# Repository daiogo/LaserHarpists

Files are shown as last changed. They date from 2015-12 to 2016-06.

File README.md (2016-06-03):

# What is a laser harp?
A laser harp is a harp that has laser beams emulating the strings of a regular harp. Whenever you intercept a laser beam, a note is played to that correspondent intercepted beam.

# Cool features in our laser harp
- The notes are played by an Android app;
- It's wireless! It communicates with the app via Bluetooth;
- There are ultrasonic range finders that measure the height of your interception;
  - That makes it possible to play 3 notes in a single laser beam.
- There are two modes of operation:
  - Free Play: let your inner Jean Michel Jarre shine (:
  - Learn To Play: learn to play a song in the harp
- RGB LED strips positioned in the front of each laser beam
  - They lit to the note you play when you intercept a laser beam on Free Play mode
  - They lit to the correspondent string and height to be intercepted in the current music

# Pics or it didn't happen
Yes, there's a demo video! Too bad we didn't had the time to learn how to play the harp (:

https://www.youtube.com/watch?v=IKeanOgFvdw

# Bill of materials
- Tiva C Launchpad
- JY-MCU Bluetooth module
- 8 HC-SR04 ultrasonic range finders
- 8 5mW laser diodes
- 8 interception sensors (circuit schematic found inside the repo)
  - comparator IC
  - potentiometer
  - LDR (Light dependent resistor)
  - 0.25W resistors
  - Materials to build a PCB to each interception sensor
- 8 12V RGB LED strips
- 3 high current drivers IC
- 3 shift registers

# Makers
- José Augustinho
  - Firmware programming, PCB confection and project manager
- Rinaldi Segecin
  - Mobile app development, firmware programming
- Diogo Freitas (myself)
  - Hardware development, PCB confection, firmware debugging

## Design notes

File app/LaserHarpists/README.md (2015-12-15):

# LaserHarpists
It's an android app that connects with a laser harp and plays sounds.

Project documented in https://www.sharelatex.com/project/56433206ea53832b060072b0

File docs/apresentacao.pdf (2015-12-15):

# LASERHARPISTS: HARPA ELETRÔNICA

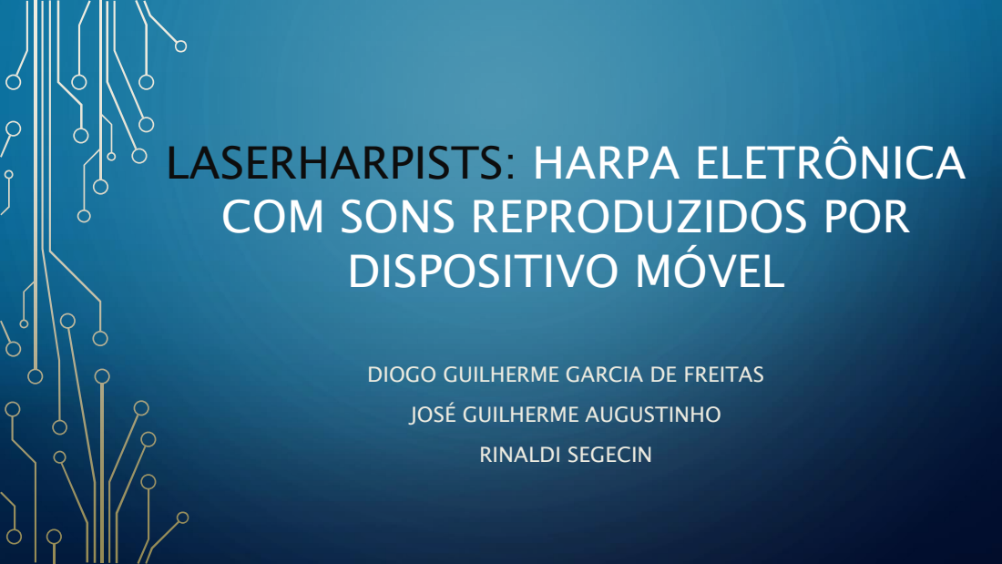
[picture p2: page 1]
RINALDI SEGECIN

COM SONS REPRODUZIDOS POR
DISPOSITIVO MÓVEL

DIOGO GUILHERME GARCIA DE FREITAS
JOSÉ GUILHERME AUGUSTINHO

## SUMÁRIO

- Introdução
- Sistema embarcado
- Visão geral
- Microcontrolador
- Módulo sensorial
- Placa principal
- Firmware
- Visão geral
- Responsabilidades
- A aplicação Android
- Modo Free Style
- Modo Learn to Play
- Resultados
- Conclusão

## INTRODUÇÃO

- Surgimento e popularização da música eletrônica
- Idealização da primeira harpa laser
- Licenciado em 1975
- Popularizado por Jean Michel Jarre
- Objetivos do projeto
- Diferenciais

## VISÃO GERAL

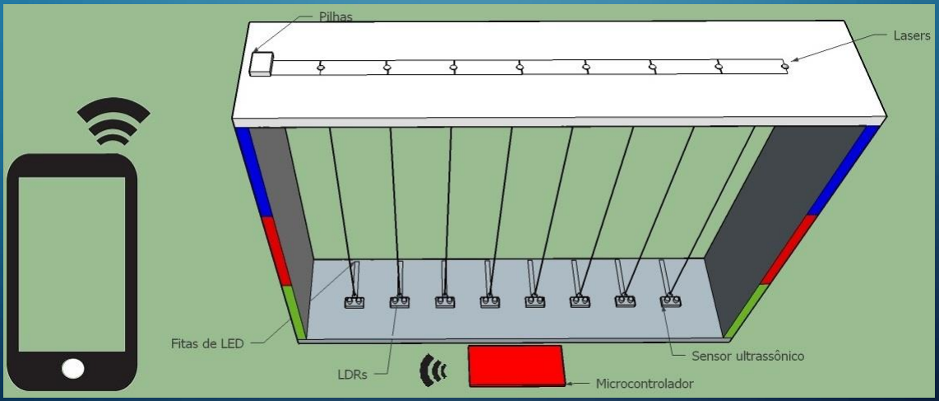
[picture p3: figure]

## SISTEMA EMBARCADO

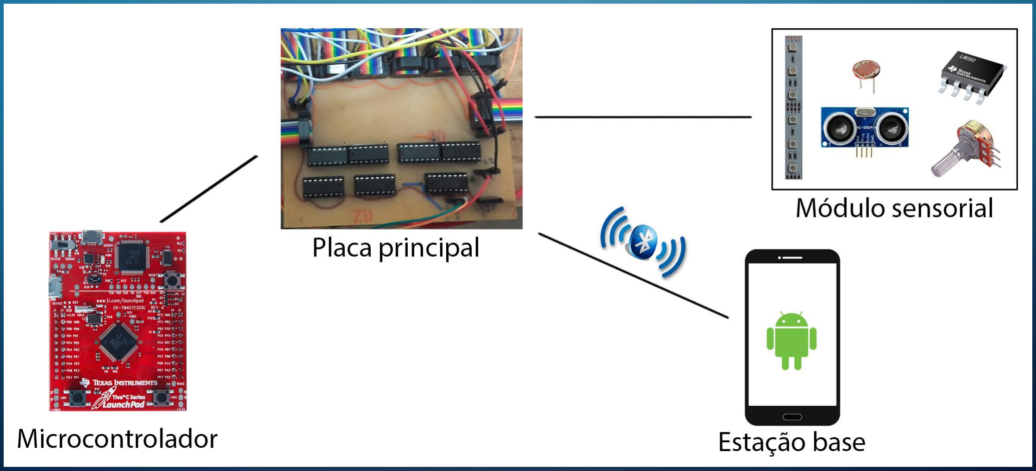
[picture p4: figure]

## MICROCONTROLADOR

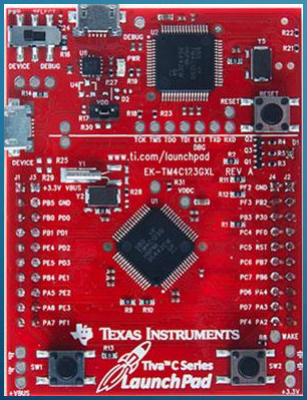
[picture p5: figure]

- Microcontrolador Tiva C
Launchpad – Texas
Instruments
- Microprocessador ARM Cortex-M4F, 32 bits
- Disponibiliza 35 pinos para uso

## MÓDULO SENSORIAL

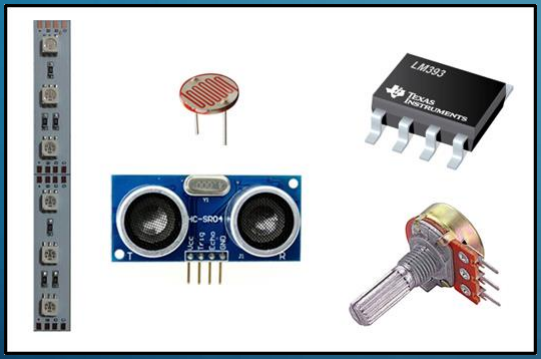
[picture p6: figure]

- Comparador de tensão LM393
- Sensores de distância HC-SR04
- Fotoresistor (LDR)
- Fita de LED’s RGB

## SENSOR DE DISTÂNCIA

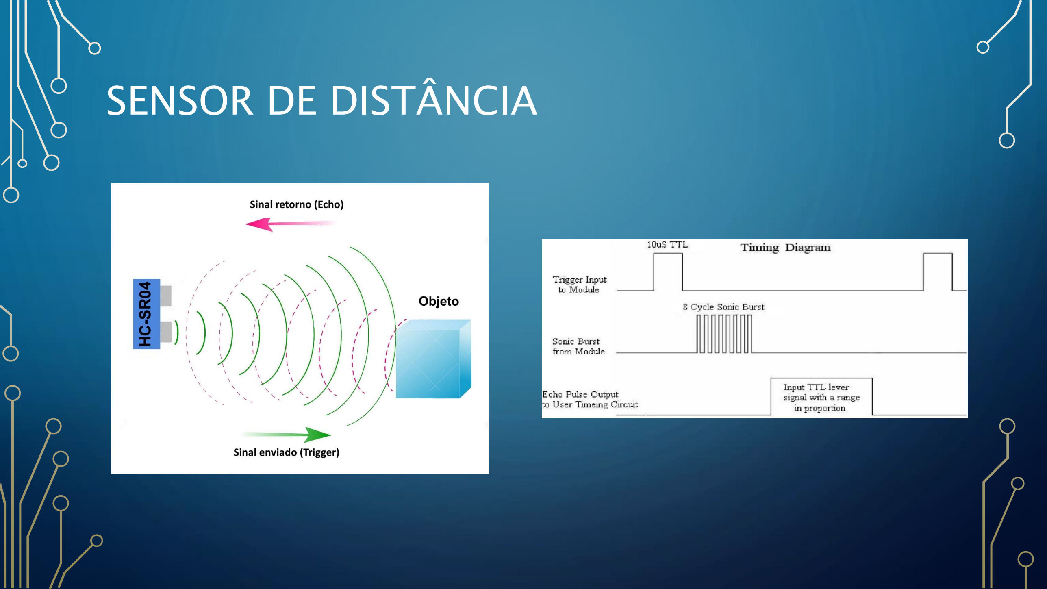
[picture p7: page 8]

## CIRCUITO DETECTOR DE INTERCEPTAÇÃO

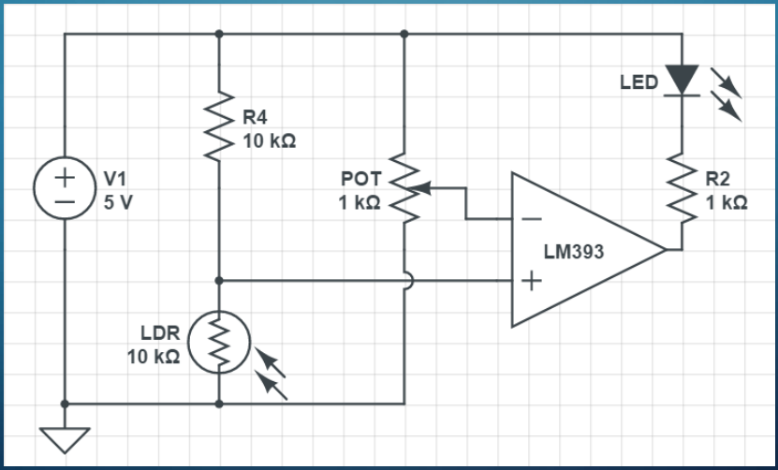
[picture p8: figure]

## MÓDULO SENSORIAL

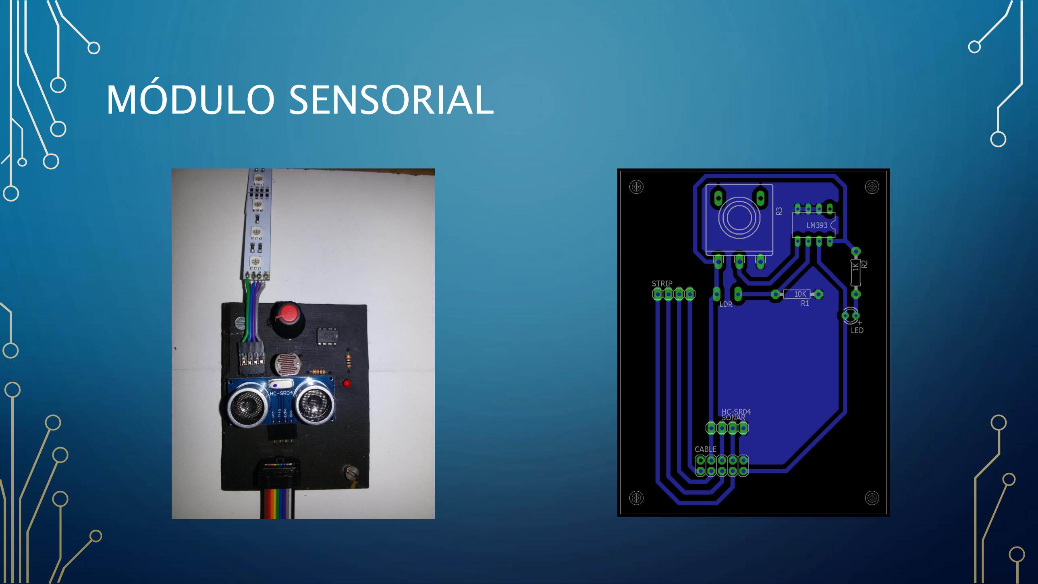
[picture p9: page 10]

## PLACA PRINCIPAL

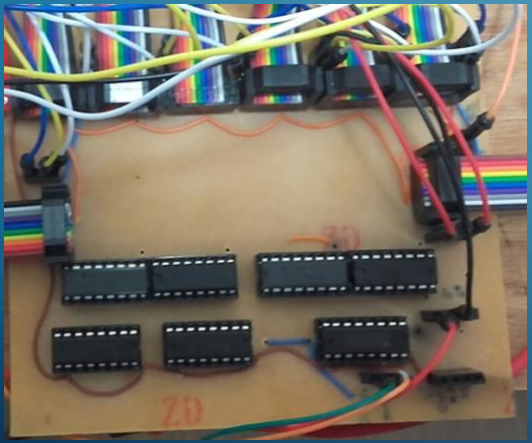
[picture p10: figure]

- Comunicador Bluetooth JY-MCU
- 3 CI’s registradores de
deslocamento (74594)
- 4 CI’s atuando como drivers de corrente (ULN2003)
- 1 CI atuando como “level shifter” (CD4050)

## PLACA PRINCIPAL- ESQUEMÁTICO

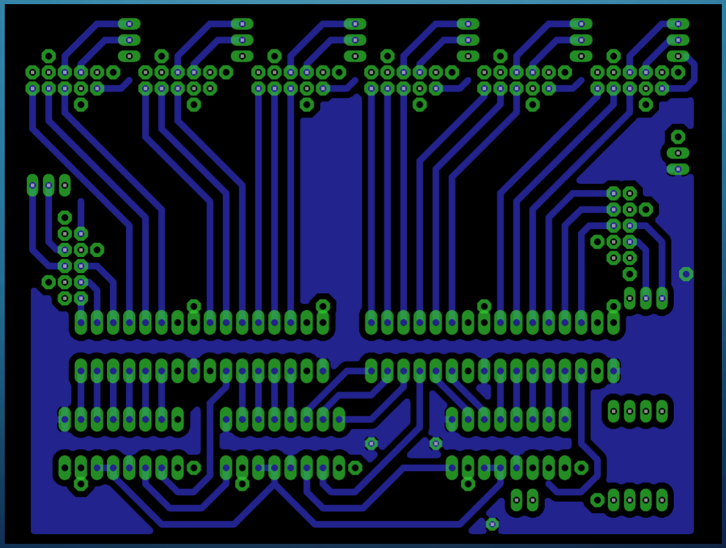
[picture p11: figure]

## FIRMWARE

- Desenvolvido através da IDE Energia
- Projeto open-source, baseada na plataforma eletrônica Arduino e no framework Wiring
- Objetivo -> habilitar o microcontrolador para comunicar-se com o dispositivo móvel utilizado pelo usuário
- Principal habilidade -> gerar e tratar interrupções

## FIRMWARE - RESPONSABILIDADES

- A detecção de interceptação nos feixes de lasers
- Determinação da altura de interceptação
- Feedback visual com as fitas LED’s
- Envio e recebimento de informações ao comunicador Bluetooth

## A APLICAÇÃO ANDROID

- Construída com auxílio do banco de dados SQLite
- Possui serviço Bluetooth sendo executado no background
- Reproduz arquivos de áudio .MIDI e .mp3

## A APLICAÇÃO ANDROID

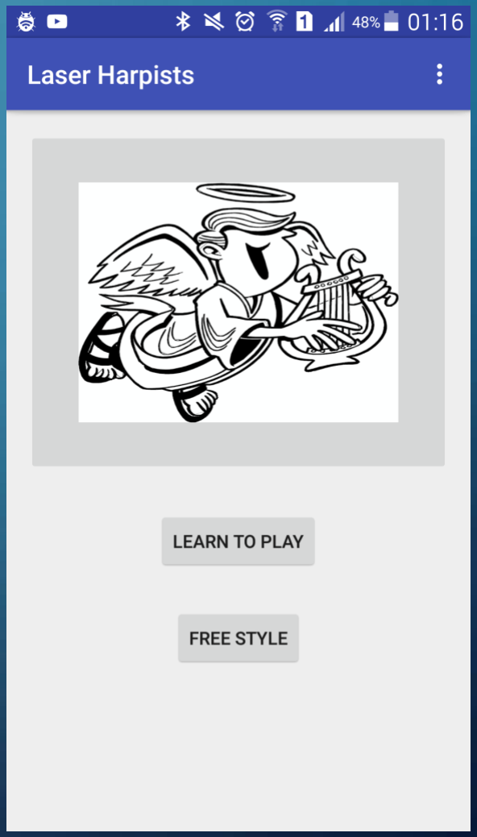
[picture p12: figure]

- Configura a harpa para dois modos de operação distintos:
- Free Style
- Learn To Play

## MODO FREE STYLE

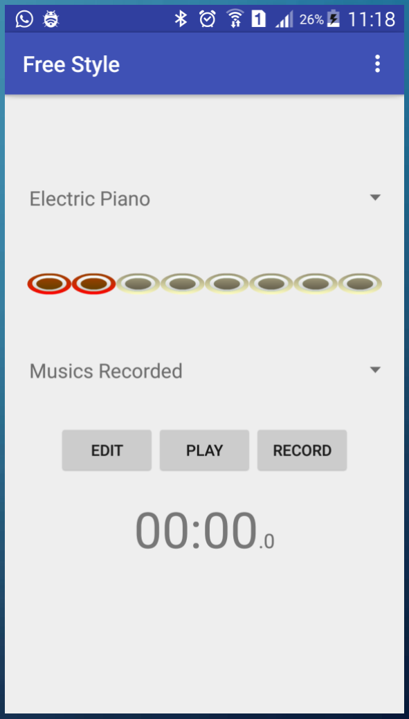
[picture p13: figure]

- Permite ao usuário tocar a harpa de maneira livre
- Capaz de gravar as canções produzidas e reproduzí-las posteriormente

## MODO FREE STYLE

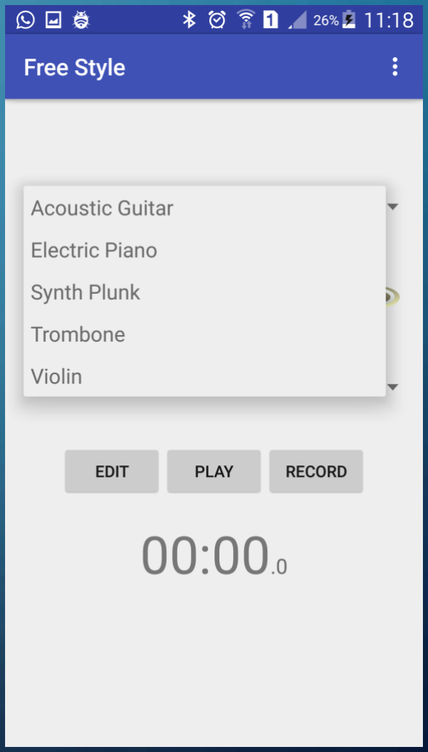
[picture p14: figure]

- Possibilita ao usuário alternar entre 6 módulos distintos:
- Violão
- Piano elétrico
- Synth Pluck
- Trombone
- Violino
- Percussão

## MODO FREE STYLE

- Todos os módulos, com exceção do Percussão, possuem 2 oitavas musicais.
- Exemplo para o módulo Violino:
| Laser 1 | Laser 2 | Laser 3 | Laser 4 | Laser 5 | Laser 6 | Laser 7 | Laser 8
Altura 3 | C5 | C#5 | D5 | D#5 | E5 | F5 | F#5 | G5
Altura 2 | G#5 | A5 | A#5 | B5 | C6 | C#6 | D6 | D#6
Altura 1 | E6 | F6 | F#6 | G6 | G#6 | A6 | A#6 | B6

## MODO LEARN TO PLAY

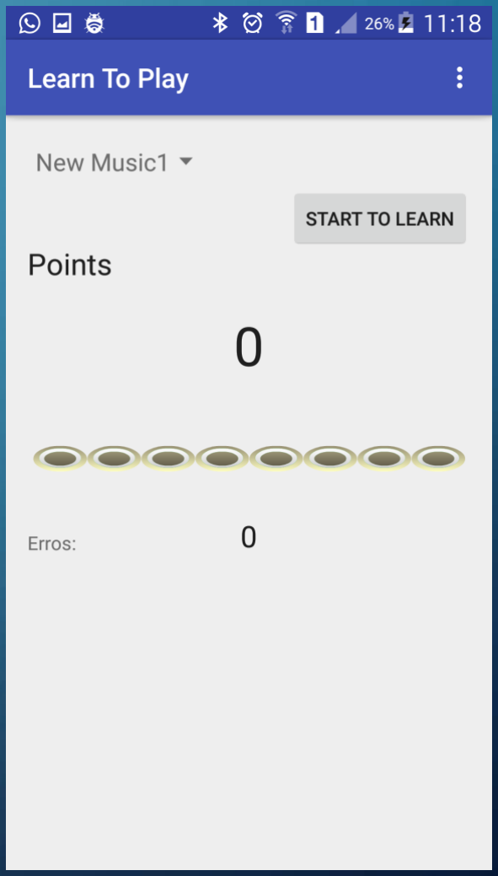
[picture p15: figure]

- Ensina o usuário a tocar músicas previamente salvas
na harpa
- Sistema de pontuação

## PROTOCOLO DE COMUNICAÇÃO

- Cordas mapeadas de A a H
- Caractere indicando início ou fim da interceptação (“i” e “o”)
- Distância da interceptação (0-67 cm)
- Exemplo
- Ai10
- Gi54
- Bo0

# RESULTADOS

## VISTA FRONTAL

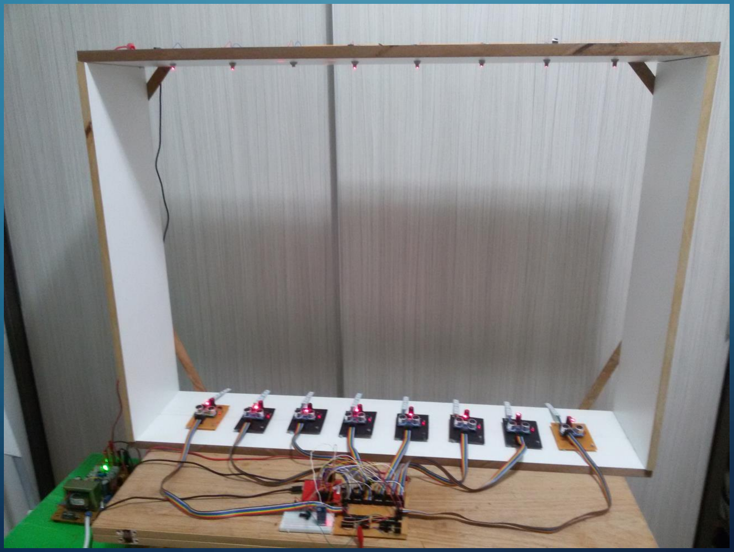
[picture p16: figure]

## MÓDULOS SENSORIAIS

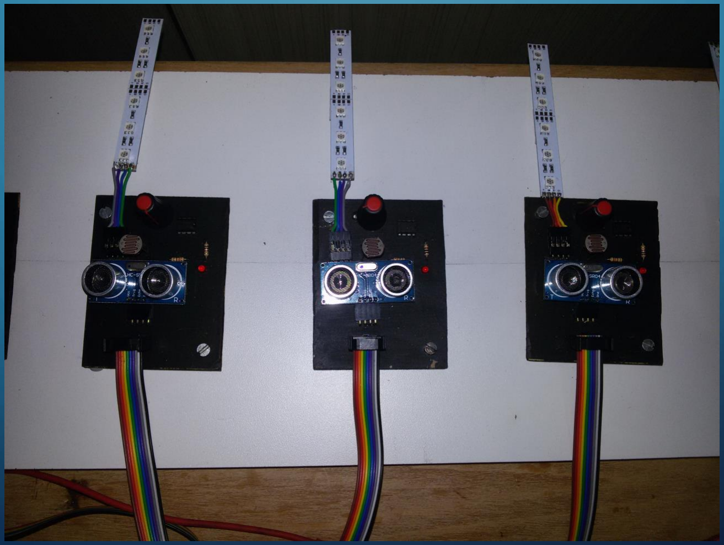
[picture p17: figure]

## DIFICULDADES ENCONTRADAS

- Visualização dos feixes de lasers
- Aprender músicas no modo Learn to Play
- Construção de um circuito detector de interceptações adequado
- Garantia de integridade de todas as conexões (> 100)
- Construção das placas de circuito impresso

## DIFICULDADES ENCONTRADAS

- Construir um aplicativo com performance aceitável
- Condições de realização de testes
- Interfaceamento com 16 sensores
- Imprecisão das medidas (superfícies não planas e luz ambiente)
- Performance e escalabilidade do firmware

## CUSTOS

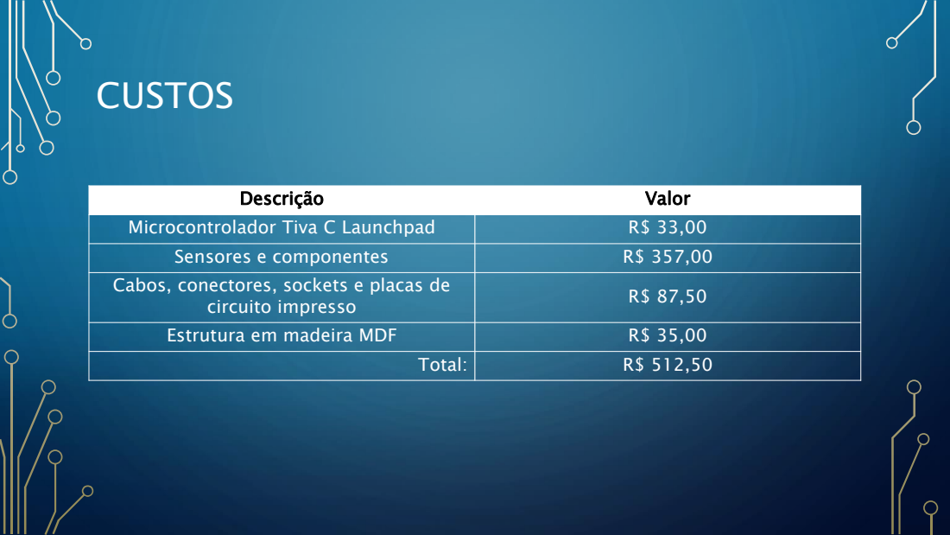
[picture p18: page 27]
Descrição; Valor

Microcontrolador Tiva C Launchpad | R$ 33,00
Sensores e componentes | R$ 357,00

Cabos, conectores, sockets e placas de circuito impresso | R$ 87,50

Estrutura em madeira MDF | R$ 35,00

Total: | R$ 512,50

## CONCLUSÃO

- Construção de um instrumento eletrônico ainda não muito difundido
- Resultados satisfatórios
- Trabalhos futuros
- Aparência e usabilidade da aplicação e da harpa
- Construção de uma placa de circuito impresso “Plug-and-Play”
- Maior variedade de módulos para o modo Free Style
- Maior quantidade de músicas disponíveis no modo Learn to Play

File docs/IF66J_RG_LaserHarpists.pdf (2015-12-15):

IF66J 2015/2 – Laser Harpists

Universidade Tecnológica Federal do Paraná – UTFPR Departamento Acadêmico de Eletrônica – DAELN Departamento Acadêmico de Informática – DAINF Engenharia de Computação
Disciplina: IF66J – Oficina de Integração 3
Semestre: 2015/2

RELATÓRIO GERENCIAL
Desenvolvimento de uma harpa eletrônica com sons reproduzidos por dispositivo móvel

Equipe:
Diogo Guilherme Garcia de Freitas / dfreitas@alunos.utfpr.edu.br
José Guilherme Augustinho / jgaugustinho@outlook.com Rinaldi Segecin / rinaldi@alunos.utfpr.edu.br

PRÉ-PROJETO

Perfil do projeto

Problema: | O crescente desenvolvimento científico e tecnológico hoje presenciado também se faz presente na música. Esta, que outrora provinha única e exclusivamente de instrumentos acústicos, atualmente já pode ser editada e produzida por meio de softwares especializados ou pelos ditos instrumentos elétricos. Nesse contexto, com a elaboração deste projeto propõese o seguinte questionamento: é possível construir uma harpa elétrica, com suas cordas substituídas por lasers, capaz de reproduzir sons de acordo com a altura em que os feixes de luz são interceptados?
Objetivo: | Construir uma harpa elétrica com lasers atuando como cordas, de forma que todo som produzido seja emitido por um dispositivo móvel, de acordo com o feixe e altura interceptados. A aplicação desenvolvida pela equipe além de ser responsável pela conexão entre o dispositivo e o instrumento, também permitirá que o usuário toque a harpa livremente ou seja instruído a tocar algumas canções. Em ambos casos, sempre haverá luzes indicadoras sinalizando cada corda e altura interceptada.

Visão Geral

1

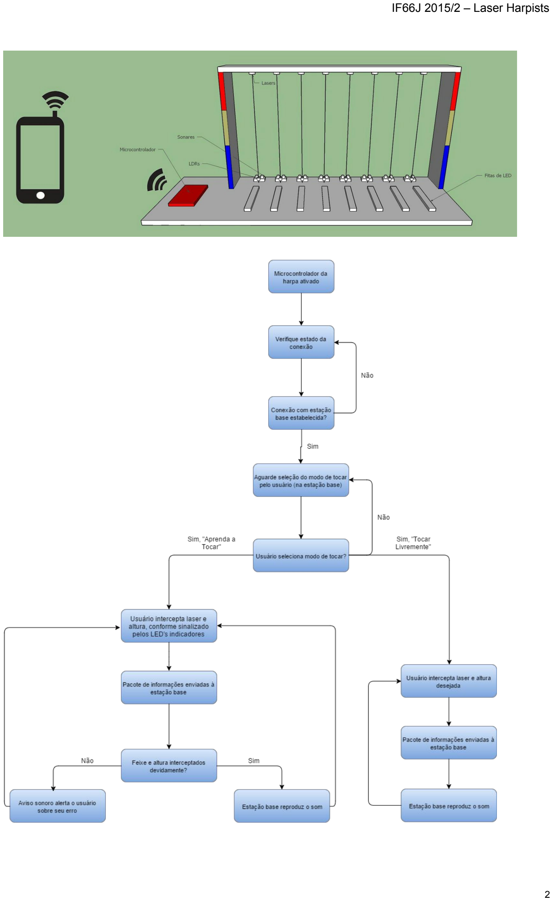
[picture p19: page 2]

2

Requisitos

Funcionais
1 | O aplicativo deverá configurar o modo de operação da harpa de acordo com a entrada do usuário, a qual deverá ser: “Aprenda a Tocar” e “Tocar Livremente”.
2 | O aplicativo deverá, no modo “Aprenda a Tocar”, ser capaz de reproduzir a música (inteira) que o usuário deseja aprender, antes ou depois deste iniciar suas lições.
3 | O aplicativo deverá, no modo “Aprenda a Tocar”, ser capaz de indicar através dos LED’s do sistema embarcado quais lasers devem ser interceptados para a música escolhida.
4 | O aplicativo deverá, no modo livre, tocar o som correspondente, assim que receber o pacote de dados do sistema embarcado.
5 | O aplicativo deverá gravar a música tocada pelo usuário, se a opção de gravar estiver acionada.
6 | O sistema embarcado deverá ser capaz de detectar uma interceptação em qualquer um dos 8 feixes de laser.
7 | O sistema embarcado deverá ser capaz de medir em que altura o feixe de laser foi interceptado.
8 | O sistema embarcado deverá acionar os LED’s correspondentes a um dado feixe, no momento que esse for interceptado.
9 | O sistema embarcado deverá enviar para a estaçãobase um pacote de dados contendo o identificador do feixe interceptado e a altura em que ele foi interceptado, assim que a interceptação ocorrer.

Não funcionais
1 | O sistema deverá ser rápido o suficiente para tocar o som assim que o laser for interceptado.
2 | O aplicativo desenvolvido para dispositivo móvel possui deverá ter como alvo o sistema operacional Android, compatível com a versão 4.1 ou superiores.
3 | A harpa não deverá ter mais de 1 metro de largura.
4 | Os sensores de distância deverão medir a altura do laser interceptado sem influenciar na medição dos sensores vizinhos.
5 | O sistema embarcado deverá se comunicar com a estaçãobase através da tecnologia Bluetooth.

3

Detalhes de implementação (expor as justificativas na apresentação)

Sistema embarcado: | Tiva C Launchpad (ARM Cortex M4) Sensores de distância HC-SR04 Fotoresistores (LDR) Módulos laser Módulo Bluetooth JY-MCU Fitas de LED’s RGB (ou similar) Comparadores de tensão LM311 (ou similar) Fonte de tensão DC 5V (dedicada para o microcontrolador) Fonte de tensão DC 5V (dedicada para os lasers) Firmware para detecção de interceptações no feixe de laser, detecção da altura da interceptação, acionamento de LED’s e comunicação com a estaçãobase
Comunicação: | Bluetooth (módulo no sistema embarcado e builtin no smartphone)
Estação base: | Dispositivo móvel Android (versão 4.1 ou superior), com aplicação desenvolvida pela equipe para comunicarse com harpa, capaz de operar nos modos “Tocar Livremente” e “Aprenda a Tocar”.

4

Perfil da equipe

Nome: | Diogo Guilherme Garcia de Freitas
Competências | Projetos com microcontroladores, eletrônica digital e analógica, desenvolvimento em linguagem C (compatível com o microcontrolador utilizado) e Java (compatível com o sistema operacional para o qual a equipe pretende desenvolver a aplicação), modelagem 3D no software Google SketchUp, organização, metódico
Funções: | Construir sistema embarcado e desenvolver firmware Modelar estrutura física do projeto Auxiliar no desenvolvimento de aplicação para dispositivo móvel com sistema operacional Android Auxiliar na construção da estrutura física da harpa
Nome: | José Guilherme Augustinho
Competências | Projetos com microcontroladores, eletrônica digital e analógica, desenvolvimento em linguagem C (compatível com o microcontrolador utilizado) e Java (compatível com o sistema operacional para o qual a equipe pretende desenvolver a aplicação), conhecimento no software de edição de imagens Adobe Photoshop, confecção de PCI’s oratória, organização, metódico.
Funções: | Gerenciar o projeto Auxiliar na construção do sistema embarcado e desenvolvimento do firmware Desenvolver aplicação para dispositivo móvel com sistema operacional Android Construir a estrutura física da harpa
Nome: | Rinaldi Segecin
Competências | Projetos com microcontroladores, eletrônica digital e analógica, desenvolvimento em linguagem C (compatível com o microcontrolador utilizado) e Java (compatível com o sistema operacional para o qual a equipe pretende desenvolver a aplicação), conhecimentos em música.
Funções: | Auxiliar na construção do sistema embarcado e desenvolvimento do firmware Desenvolver aplicação para dispositivo móvel com sistema operacional Android Auxiliar na construção da estrutura física da harpa

5

Análise de riscos

1º ETAPA: IDENTIFICAÇÃO DO RISCO
Denominação do risco:Aquisição do sensor HC-SR04
Descrição do Risco:
O sensor de distância pode ser adquirido por um valor inferior se comprado no exterior, porém correse o risco de haver muito atraso na entrega.
2º ETAPA: AVALIAÇÃO DO RISCO
Impacto: | Alto:( ) | Médio/Alto:(X) | Médio:( ) | Médio/Baixo:( ) | Baixo:( )
Explique: Este sensor é muito importante para o projeto. Caso a entrega atrase, deveráse comprálo no Brasil por um preço maior.
Probabilidade: | Alto:( ) | Médio/Alto:(X) | Médio:( ) | Médio/Baixo:( ) | Baixo: ( )
Explique: A equipe tem experiência com a importação de componentes e sabe que geralmente os tempos de entrega variam entre 3 e 8 semanas.
3º ETAPA: RESPOSTA AO RISCO
Estratégias e Ações: Comprar de fornecedores nacionais (já foi feita a pesquisa de disponibilidade no mercado).

1º ETAPA: IDENTIFICAÇÃO DO RISCO
Denominação do risco:Qualidade das medições do sensor de distância HC-SR04 Descrição do Risco:
O sensor em questão é de baixo custo e, portanto, pode apresentar medições de qualidade abaixo do desejado.
2º ETAPA: AVALIAÇÃO DO RISCO
Impacto: | Alto:( ) | Médio/Alto:( ) | Médio:(X) | Médio/Baixo:( ) | Baixo:( )
Explique: Um membro da equipe já trabalhou com este sensor e relata ter, esporadicamente, algumas medidas incoerentes com a realidade.
Probabilidade: | Alto:( ) | Médio/Alto:( ) | Médio:( ) | Médio/Baixo:( ) | Baixo: (X)
Explique: Os testes unitários realizados com o sensor indicam que as medições deverão ter qualidade suficiente para a aplicação.
3º ETAPA: RESPOSTA AO RISCO
Estratégias e Ações: Procurar as fontes de ruído do sensor e achar mecanismos para evitar as interferências e medições erradas. Em último caso, trocar de sensor.

1º ETAPA: IDENTIFICAÇÃO DO RISCO
Denominação do risco:Número de cordas na harpa e dificuldade para tocar o instrumento Descrição do Risco:
O número de cordas escolhido para a harpa poderá representar uma dificuldade na hora de tocála, uma vez que as oitavas não estariam em sequência.
2º ETAPA: AVALIAÇÃO DO RISCO
Impacto: | Alto:( ) | Médio/Alto:( ) | Médio:(X) | Médio/Baixo:( ) | Baixo:( )
Explique: A dificuldade em tocar a harpa não depende apenas da qualidade ou sofisticação do projeto, mas também das habilidades do usuário, como em todo instrumento musical.
Probabilidade: | Alto:( ) | Médio/Alto:( ) | Médio:(X) | Médio/Baixo:( ) | Baixo: ( )
Explique: É difícil mensurar a complexidade de tocar um instrumento sem têlo experimentado antes.
3º ETAPA: RESPOSTA AO RISCO
Estratégias e Ações: Construir uma harpa com as escalas em sequência, usando mais feixes de laser e mais sensores.

6

1º ETAPA: IDENTIFICAÇÃO DO RISCO
Denominação do risco:Construção dos módulos de sensoriamento
Descrição do Risco:
O número de cordas é muito grande e o número de sensores também. O projeto prevê a construção de placas de circuito impresso de módulos de sensoriamento para cada corda da harpa.
2º ETAPA: AVALIAÇÃO DO RISCO
Impacto: | Alto:( ) | Médio/Alto:( ) | Médio:( ) | Médio/Baixo:(X) | Baixo:( )
Explique: As PCI's feitas artesanalmente podem não sair exatamente iguais e podem funcionar da maneira diferente uma da outra, pois um elevado número delas precisará ser produzido.
Probabilidade: | Alto:( ) | Médio/Alto:( ) | Médio:( ) | Médio/Baixo:(X) | Baixo: ( )
Explique: Uma vez realizado um projeto de PCI, podese prototipálo para realizar testes e verificar a qualidade do projeto, se funciona de acordo com o especificado ou não.
3º ETAPA: RESPOSTA AO RISCO
Estratégias e Ações: Requerer a construção das PCI's por um laboratório especializado ou utilizar apenas cabos comuns para fazer as conexões entre os sensores e o microcontrolador.

1º ETAPA: IDENTIFICAÇÃO DO RISCO
Denominação do risco:Comunicação Bluetooth com baixa taxa de transferência
Descrição do Risco:
O módulo Bluetooth JY-MCU nunca foi utilizado pela equipe e, portanto, não se sabe se o mesmo é capaz de transmitir a informação necessária na velocidade desejada.
2º ETAPA: AVALIAÇÃO DO RISCO
Impacto: | Alto:( ) | Médio/Alto:(X) | Médio:( ) | Médio/Baixo:( ) | Baixo:( )
Explique: Se a velocidade não for suficiente, deveremos buscar um módulo de comunicação de melhor qualidade. Do contrário, o som será tocado com atraso.
Probabilidade: | Alto:( ) | Médio/Alto:( ) | Médio:( ) | Médio/Baixo:(X) | Baixo: ( )
Explique: Sabese que a quantidade de dados a ser enviada à estaçãobase está na ordem de centenas de bytes, enquanto que a tecnologia Bluetooth é capaz de transferir dados em uma velocidade na ordem de megabytes por segundo.
3º ETAPA: RESPOSTA AO RISCO
Estratégias e Ações: Testar os limites de transferência de dados do módulo, pesquisar métodos de comunicação alternativos.

1º ETAPA: IDENTIFICAÇÃO DO RISCO
Denominação do risco:Não conseguir tocar mais de um arquivo de áudio ao mesmo tempo. Descrição do Risco: Quando o usuário tocar mais que uma nota ao mesmo tempo o dispositivo Android deverá tocar as notas correspondentes sem que as outras notas parem de tocar.
2º ETAPA: AVALIAÇÃO DO RISCO
Impacto: | Alto:( ) | Médio/Alto:( ) | Médio:(X) | Médio/Baixo:( ) | Baixo:( )
Explique: A qualidade do som resultante tocado no smartphone não será fiel com o resultado esperado de se tocar duas notas ao mesmo tempo.
Probabilidade: | Alto:( ) | Médio/Alto:( ) | Médio:( ) | Médio/Baixo:( ) | Baixo: (X)
Explique: No sistema operacional Android é possível criar múltiplas instâncias para tocaram áudio em diferentes threads, possibilitando a mixagem dos sons.
3º ETAPA: RESPOSTA AO RISCO
Estratégias e Ações:Tocar cada nota requisitada numa thread diferente.

7

Cronograma

Atividade | Início | Fim | %
1 | Apresentação da disciplina e definição de equipes | 19/08/2015 | 19/08/2015 | 100
2 | Apresentação das propostas de projeto | 19/08/2015 | 26/08/2015 | 100
3 | Reapresentação das propostas de projeto e redefinição das equipes | 26/08/2015 | 02/09/2015 | 100
4 | Especificação e pesquisa de viabilidade do projeto para defesa e delimitação de um tema | 02/09/2015 | 09/09/2015 | 100
5 | Delimitação do microcontrolador a ser utilizado, quantidade de lasers e número de interceptações possíveis de serem feitas em cada feixe | 09/09/2015 | 19/09/2015 | 100
6 | Testes unitários com cada componente do sistema embarcado | 09/09/2015 | 28/10/2015 | 5
7 | Pesquisa e testes de API’s e bibliotecas para o desenvolvimento do aplicativo | 09/09/2015 | 28/10/2015 | 5
8 | Elaboração do préprojeto | 19/09/2015 | 25/09/2015 | 75
9 | Pesquisa de sons para serem tocados no aplicativo | 23/09/2015 | 28/10/2015 | 0
10 | Desenvolvimento do aplicativo | 10/10/2015 | 22/11/2015 | 0
11 | Construção do firmware | 10/10/2015 | 22/11/2015 | 0
12 | Testes dos sistemas integrados | 11/11/2015 | 22/11/2015 | 0
13 | Construção da estrutura física da harpa | 11/11/2015 | 22/11/2015 | 0
14 | Testes e ajustes finais para a apresentação e gravação do vídeo | 22/11/2015 | 25/11/2015 | 0

8

Entregas (AV1, AV2, AV3, AV4)

Entrega 1 (AV1) (apenas estes 5 itens obrigatórios)

Bases teóricas (obrigatório)
Reavaliação de riscos (obrigatório)
Acompanhamento do cronograma (obrigatório)
Dificuldades (obrigatório)
Atividades futuras (obrigatório)

Entrega 2 (AV2)

Teste unitário dos periféricos funcionando
Projeto do módulo sensorial
Projeto do módulo de lasers
Conclusão das funcionalidades básicas do aplicativo (não integradas) Repositório de sons a serem executados pelo aplicativo
Acompanhamento do cronograma (obrigatório)
Dificuldades (obrigatório)
Atividades futuras (obrigatório)

Entrega 3 (AV3)

Projeto de PCI
Entrega parcial do firmware
Demonstração parcial dos testes de integração Demonstração parcial do aplicativo
Acompanhamento do cronograma (obrigatório)
Dificuldades (obrigatório)
Atividades futuras (obrigatório)

Entrega 4 (AV4) (apenas estes 3 itens obrigatórios)

Demonstração do funcionamento final em um video 3 minutos. (obrigatório) Apresentação em power point de toda a equipe (max. de 20 min.). (obrigatório)
Custos reais do projeto. (obrigatório)

9

### 1. ENTREGA 1 (AV1)

### 1.1 Bases teóricas

CRAB, Saimon. 120 Years of Electronic Music. Disponível em: <http://120years.net/>. Acesso em: 1 de outrubro de 2015.
Fornece informações sobre a história da música eletrônica, entre os anos de 1800 e 1990, e os instrumentos que caracterizam este período.
Aborda as diferentes maneiras de se produzir música eletrônica com os recursos e sofisticações de cada época.

HOLMES, Thom. Electronic and Experimental Music. 2th ed. New York: Routledge, 2002.
Informa sobre a história da música eletrônica, abordando os principais compositores e gêneros musicais.
Técnicas sobre a sintetização analógica e digital de sons.

VALVANO, Jonathan W. Embedded Systems: Introduction to the ARM® Cortex(TM)-M Microcontrollers.5th ed. CreateSpace Independent Publishing Platform, 2012
Informa sobre a arquitetura interna dos microcontroladores ARM da série Cortex-M.
Especifica a linguagem Assembly do microcontrolador e o processo desenvolvimento e debug de firmware.
Detalha todo o funcionamento do microcontrolador e como este pode interagir com o mundo externo.

YIU, Joseph. The Definitive Guide to ARM® Cortex®-M3 and Cortex®-M4 Processors. 3th ed. Cambridge: Newnes, 2014.
Informa sobre a arquitetura interna dos microcontroladores ARM da série Cortex-M.
Especifica a linguagem Assembly do microcontrolador e o processo desenvolvimento e debug de firmware.
Detalha todo o funcionamento dos microcontroladores Cortex-M3 e Cortex-M4 e como estes pode interagir com o mundo externo.

MURPHY, Mark L. The Busy Coder's Guide to Android Development. CommonsWare, 2013.
Todos os passos e ferramentas necessários para iniciar o desenvolvimento na IDE selecionada.
Informa sobre os diversos componentes de uma aplicação Android (manifests, resources, activitys, entre outros) ao mesmo tempo que desenvolve um aplicativo completo, de maneira incremental.

LEE, Wei-Meng. Android Application Development CookBook:93 recipes for building winning apps. Wrox, 2013.
Como utilizar Views para construir a interface para o usuário.

10

Aborda tópicos sobre como conectar a aplicação Android com o mundo exterior, como web services, programação de sockets, bluetooth, entre outros. Como acessar e fazer uso do hardware do dispositivo móvel.

SMYTH, Neil. Android Studio Development Essentials.Techotopia, 2014.
Informações sobre o ambiente de desenvolvimento Android Studio, como configurar o ambiente para desenvolvimento e testes.
Aborda como todos os componentes de uma aplicação Android se relacionam com o ambiente Android Studio.

FELDSTEIN, Sandy. Practical Theory Complete: a selfinstruction music theory course. Alfred Music, 1982.
Aborda de maneira didática tópicos básicos da teoria musical (pentagrama, claves, unidades de tempo e compasso, pausas e repetições).
Informa sobre escalas musicais e acordes.

CARDOSO, Belmira; MASCARENHAS, Mário. Curso Completo de Teoria Musical e Solfejo. 8ª ed. Irmãos Vitale.
Aborda de maneira didática tópicos básicos da teoria musical (pentagrama, claves, unidades de tempo e compasso, pausas e repetições).
Informa sobre escalas musicais e acordes.

11

### 1.2 Reavaliação de riscos

1º ETAPA: IDENTIFICAÇÃO DO RISCO
Denominação do risco:Aquisição do sensor HC-SR04
Descrição do Risco:
O sensor de distância pode ser adquirido por um valor inferior se comprado no exterior, porém correse o risco de haver muito atraso na entrega.
2º ETAPA: AVALIAÇÃO DO RISCO
Impacto: | Alto:(X) | Médio/Alto:( ) | Médio:( ) | Médio/Baixo:( ) | Baixo:( )
Explique: Este sensor é muito importante para o projeto. Caso a entrega atrase, deveráse comprálo no Brasil por um preço maior.
Probabilidade: | Alto:(X) | Médio/Alto:( ) | Médio:( ) | Médio/Baixo:( ) | Baixo: ( )
Explique: A equipe tem experiência com a importação de componentes e sabe que geralmente os tempos de entrega variam entre 3 e 8 semanas.
3º ETAPA: RESPOSTA AO RISCO
Estratégias e Ações: Comprar de fornecedores nacionais (já foi feita a pesquisa de disponibilidade no mercado).

1º ETAPA: IDENTIFICAÇÃO DO RISCO
Denominação do risco:Qualidade das medições do sensor de distância HC-SR04 Descrição do Risco:
O sensor em questão é de baixo custo e, portanto, pode apresentar medições de qualidade abaixo do desejado.
2º ETAPA: AVALIAÇÃO DO RISCO
Impacto: | Alto:( ) | Médio/Alto:( ) | Médio:(X) | Médio/Baixo:( ) | Baixo:( )
Explique: Um membro da equipe já trabalhou com este sensor e relata ter, esporadicamente, algumas medidas incoerentes com a realidade.
Probabilidade: | Alto:( ) | Médio/Alto:( ) | Médio:( ) | Médio/Baixo:( ) | Baixo: (X)
Explique: Os testes unitários realizados com o sensor indicam que as medições deverão ter qualidade suficiente para a aplicação.
3º ETAPA: RESPOSTA AO RISCO
Estratégias e Ações: Procurar as fontes de ruído do sensor e achar mecanismos para evitar as interferências e medições erradas. Em último caso, trocar de sensor.

1º ETAPA: IDENTIFICAÇÃO DO RISCO
Denominação do risco:Número de cordas na harpa e dificuldade para tocar o instrumento Descrição do Risco:
O número de cordas escolhido para a harpa poderá representar uma dificuldade na hora de tocála, uma vez que as oitavas não estariam em sequência.
2º ETAPA: AVALIAÇÃO DO RISCO
Impacto: | Alto:( ) | Médio/Alto:( ) | Médio:(X) | Médio/Baixo:( ) | Baixo:( )
Explique: A dificuldade em tocar a harpa não depende apenas da qualidade ou sofisticação do projeto, mas também das habilidades do usuário, como em todo instrumento musical.
Probabilidade: | Alto:( ) | Médio/Alto:( ) | Médio:(X) | Médio/Baixo:( ) | Baixo: ( )
Explique: É difícil mensurar a complexidade de tocar um instrumento sem têlo experimentado antes.
3º ETAPA: RESPOSTA AO RISCO
Estratégias e Ações: Construir uma harpa com as escalas em sequência, usando mais feixes de laser e mais sensores.

1º ETAPA: IDENTIFICAÇÃO DO RISCO
Denominação do risco:Construção dos módulos de sensoriamento
Descrição do Risco:

12

O número de cordas é muito grande e o número de sensores também. O projeto prevê a construção de placas de circuito impresso de módulos de sensoriamento para cada corda da harpa.
2º ETAPA: AVALIAÇÃO DO RISCO
Impacto: | Alto:( ) | Médio/Alto:( ) | Médio:( ) | Médio/Baixo:(X) | Baixo:( )
Explique: As PCI's feitas artesanalmente podem não sair exatamente iguais e podem funcionar da maneira diferente uma da outra, pois um elevado número delas precisará ser produzido.
Probabilidade: | Alto:( ) | Médio/Alto:( ) | Médio:( ) | Médio/Baixo:(X) | Baixo: ( )
Explique: Uma vez realizado um projeto de PCI, podese prototipálo para realizar testes e verificar a qualidade do projeto, se funciona de acordo com o especificado ou não.
3º ETAPA: RESPOSTA AO RISCO
Estratégias e Ações: Requerer a construção das PCI's por um laboratório especializado ou utilizar apenas cabos comuns para fazer as conexões entre os sensores e o microcontrolador.

1º ETAPA: IDENTIFICAÇÃO DO RISCO
Denominação do risco:Comunicação Bluetooth com baixa taxa de transferência
Descrição do Risco:
O módulo Bluetooth JY-MCU nunca foi utilizado pela equipe e, portanto, não se sabe se o mesmo é capaz de transmitir a informação necessária na velocidade desejada.
2º ETAPA: AVALIAÇÃO DO RISCO
Impacto: | Alto:( ) | Médio/Alto:(X) | Médio:( ) | Médio/Baixo:( ) | Baixo:( )
Explique: Se a velocidade não for suficiente, deveremos buscar um módulo de comunicação de melhor qualidade. Do contrário, o som será tocado com atraso.
Probabilidade: | Alto:( ) | Médio/Alto:( ) | Médio:( ) | Médio/Baixo:(X) | Baixo: ( )
Explique: Sabese que a quantidade de dados a ser enviada à estaçãobase está na ordem de centenas de bytes, enquanto que a tecnologia Bluetooth é capaz de transferir dados em uma velocidade na ordem de megabytes por segundo.
3º ETAPA: RESPOSTA AO RISCO
Estratégias e Ações: Testar os limites de transferência de dados do módulo, pesquisar métodos de comunicação alternativos.

1º ETAPA: IDENTIFICAÇÃO DO RISCO
Denominação do risco:Não conseguir tocar mais de um arquivo de áudio ao mesmo tempo. Descrição do Risco: Quando o usuário tocar mais que uma nota ao mesmo tempo o dispositivo Android deverá tocar as notas correspondentes sem que as outras notas parem de tocar.
2º ETAPA: AVALIAÇÃO DO RISCO
Impacto: | Alto:( ) | Médio/Alto:( ) | Médio:(X) | Médio/Baixo:( ) | Baixo:( )
Explique: A qualidade do som resultante tocado no smartphone não será fiel com o resultado esperado de se tocar duas notas ao mesmo tempo.
Probabilidade: | Alto:( ) | Médio/Alto:( ) | Médio:( ) | Médio/Baixo:( ) | Baixo:(X)
Explique: No sistema operacional Android é possível criar múltiplas instâncias para tocaram áudio em diferentes threads, possibilitando a mixagem dos sons.
3º ETAPA: RESPOSTA AO RISCO
Estratégias e Ações:Tocar cada nota requisitada numa thread diferente.

1º ETAPA: IDENTIFICAÇÃO DO RISCO
Denominação do risco: Não conseguir estabelecer comunicação entre o smartphone e o sistema embarcado com o módulo Bluetooth.
Descrição do Risco: A equipe pode ter dificuldades em fazer a comunicação sem fio funcionar, seja a dificuldade em configurar a comunicação serial ou em identificar se o módulo é defeituoso. 2º ETAPA: AVALIAÇÃO DO RISCO
Impacto: | Alto:(X) | Médio/Alto:( ) | Médio:( ) | Médio/Baixo:( ) | Baixo:( )

13

Explique: A comunicação sem fio é prérequisito para a aceitação do projeto. Se ela não funcionar, o projeto não terá cumprido o que foi prometido.
Probabilidade: | Alto:( ) | Médio/Alto:(X) | Médio:( ) | Médio/Baixo:( ) | Baixo:( )
Explique:Os testes iniciais já mostraram que isto é um risco e uma dificuldade válida.
3º ETAPA: RESPOSTA AO RISCO
Estratégias e Ações: Procurar outras opções de módulo Bluetooth e em último caso trocar o método de comunicação sem fio (Wi-Fi).

14

### 1.3 Acompanhamento do cronograma

Atividade | Início | Fim | %
1 | Apresentação da disciplina e definição de equipes | 19/08/2015 | 19/08/2015 | 100
2 | Apresentação das propostas de projeto | 19/08/2015 | 26/08/2015 | 100
3 | Reapresentação das propostas de projeto e redefinição das equipes | 26/08/2015 | 02/09/2015 | 100
4 | Especificação e pesquisa de viabilidade do projeto para defesa e delimitação de um tema | 02/09/2015 | 09/09/2015 | 100
5 | Delimitação do microcontrolador a ser utilizado, quantidade de lasers e número de interceptações possíveis de serem feitas em cada feixe | 09/09/2015 | 19/09/2015 | 100
6 | Testes unitários com cada componente do sistema embarcado (testes com sonares, LDRs, envio de dados pelo Bluetooth) | 09/09/2015 | 28/10/2015 | 15
7 | Pesquisa e testes de API’s e bibliotecas para o desenvolvimento do aplicativo (testes para tocar áudio, receber dados pelo Bluetooth, construção de interface) | 09/09/2015 | 28/10/2015 | 10
8 | Elaboração do préprojeto | 19/09/2015 | 25/09/2015 | 100
9 | Pesquisa de sons para serem tocados no aplicativo | 23/09/2015 | 28/10/2015 | 5
10 | Desenvolvimento do aplicativo | 10/10/2015 | 22/11/2015 | 0
11 | Construção do firmware | 10/10/2015 | 22/11/2015 | 0
12 | Testes dos sistemas integrados | 11/11/2015 | 22/11/2015 | 0
13 | Construção da estrutura física da harpa | 11/11/2015 | 22/11/2015 | 0
14 | Testes e ajustes finais para a apresentação e gravação do vídeo | 22/11/2015 | 25/11/2015 | 0

15

### 1.4 Dificuldades

01
Dificuldade: Configuração e implementação da comunicação serial no ambiente de desenvolvimento Energia
Solução:Pesquisar métodos alternativos para fazer a comunicação serial no ambiente. Em último caso, estudar os efeitos e novas dificuldades de migrar o desenvolvimento do firmware para a linguagem C.

02
Dificuldade: Reconhecer se o módulo Bluetooth está defeituoso ou não Solução:Seguir tutoriais passo a passo encontrados na internet sem modificação dos passos e sem adaptálos para outras plataformas. Se não funcionar, há uma grande chance de o módulo estar estragado. Se isso se confirmar, partir para outras opções de módulo Bluetooth.

03
Dificuldade: Construção do circuito de sensoriamento com o LDR Solução:Pesquisar diferentes circuitos integrados comparadores de tensão para conseguir a discretização do sinal analógico em um sinal digital. Como os CI’s TL071 e o LM311 se mostraram inapropriados, a equipe irá realizar testes com o CI LM339.

04
Dificuldade: Encontrar arquivos de áudio para serem reproduzidos no aplicativo
Solução:Uma quantidade considerável de pesquisa sobre arquivos MIDI não rendeu muitos frutos uma vez que poucos resultados foram encontrados. Passouse então a procurar também arquivos em mp3, pois acreditase que estes também podem ser reproduzidos facilmente no smartphone.

16

### 1.5 Atividades futuras

1 | Teste do módulo Bluetooth (simples envio e recebimento de dados) e análise das taxas de transmissão.
2 | Design do circuito de sensoriamento para os LDR’s.
3 | Teste do circuito de sensoriamento dos LDR’s (análise de efeitos da luminosidade no ambiente).
4 | Design do módulo sensorial para cada feixe de laser (sonar + LDR + fita LED).
5 | Teste do módulo sensorial e análise do seu comportamento quando próximo de outros módulos.
6 | Pesquisa dos arquivos de áudio a serem tocados pela harpa.
7 | Construção de um repositório de áudio.
8 | Teste de reprodução de arquivos de áudio no sistema Android.
9 | Desenvolvimento parcial do módulo “Tocar Livremente” da aplicação Android, capaz de reproduzir sons quando interceptado um número reduzido de lasers.
10 | Desenvolvimento parcial do módulo “Aprenda a Tocar” da aplicação Android.

17

### 2. ENTREGA 2 (AV2)

### 2.1 Teste unitário dos periféricos funcionando

Pesquisa de códigos de exemplo para teste dos sonares
Teste de funcionamento e leitura de cada um dos sonares
Teste do circuito de detecção de interceptação no feixe (ver seção 2.2)
Teste da comunicação Bluetooth bidirecional entre o embarcado e o smartphone
Teste do funcionamento da fita LED (realizado mas não atingido)
Teste de integração com todos os periféricos para simulação de um corda na harpa (detecção de interceptação, leitura do sonar e envio dos dados da interceptação para o smartphone)

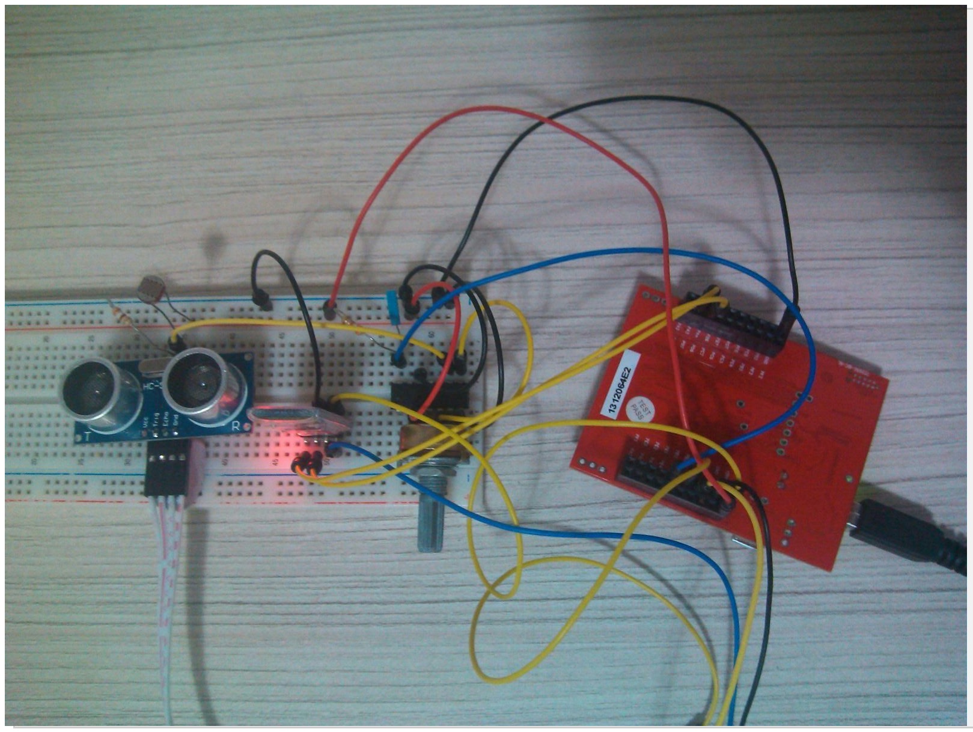
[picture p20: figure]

Protótipo do módulo sensorial integrado.

### 2.2 Projeto do módulo sensorial

Teste da variação de resistência de um LDR sobre a incidência de um laser Pesquisa de uma solução para discretizar a leitura do LDR
Construção e teste do circuito proposto em ambiente claro e escuro
Desenvolvimento de código para interfacear o embarcado com o módulo
Integração do módulo com o embarcado para simular o funcionamento de uma corda da harpa

18

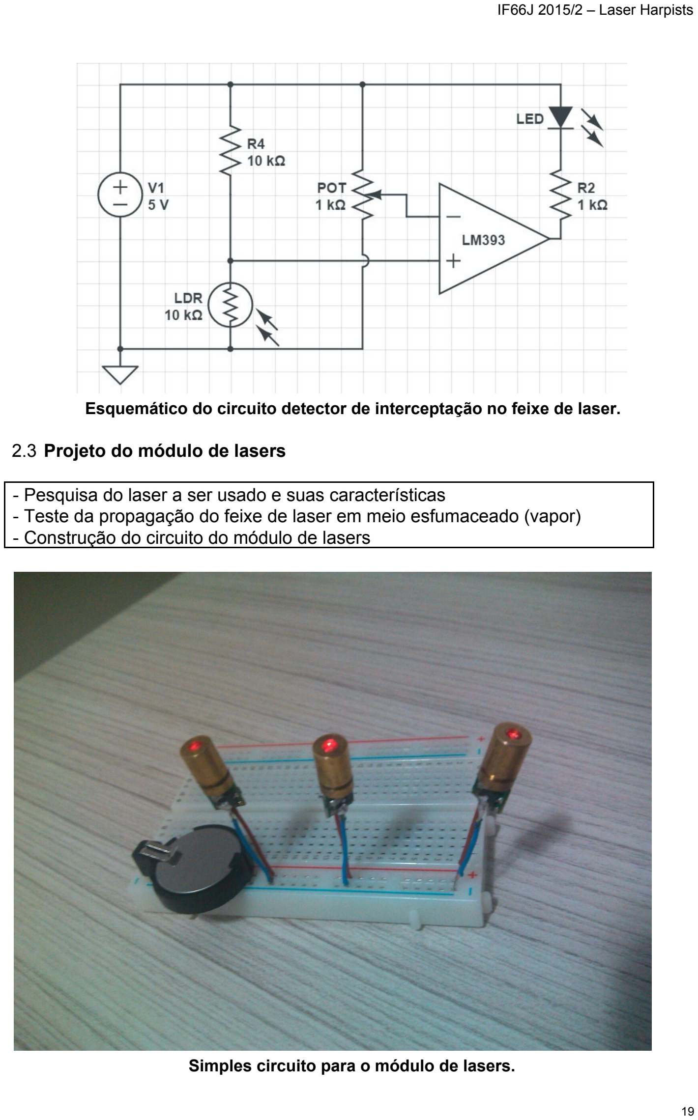
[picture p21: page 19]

Esquemático do circuito detector de interceptação no feixe de laser.

2.3 Projeto do módulo de lasers

Pesquisa do laser a ser usado e suas características
Teste da propagação do feixe de laser em meio esfumaceado (vapor) Construção do circuito do módulo de lasers

Simples circuito para o módulo de lasers.

19

2.4 Conclusão das funcionalidades básicas do aplicativo (não integradas)

Pesquisa e teste de código para reprodução de arquivos MIDI e mp3 no smartphone
Pesquisa e teste de código para envio e recebimento de dados através da comunicação Bluetooth

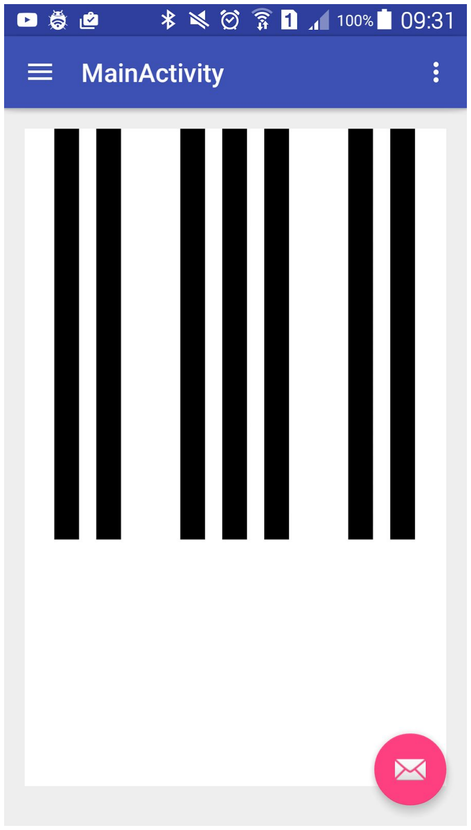
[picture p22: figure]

Aplicação desenvolvida para teste de reprodução de arquivos MIDI e mp3

20

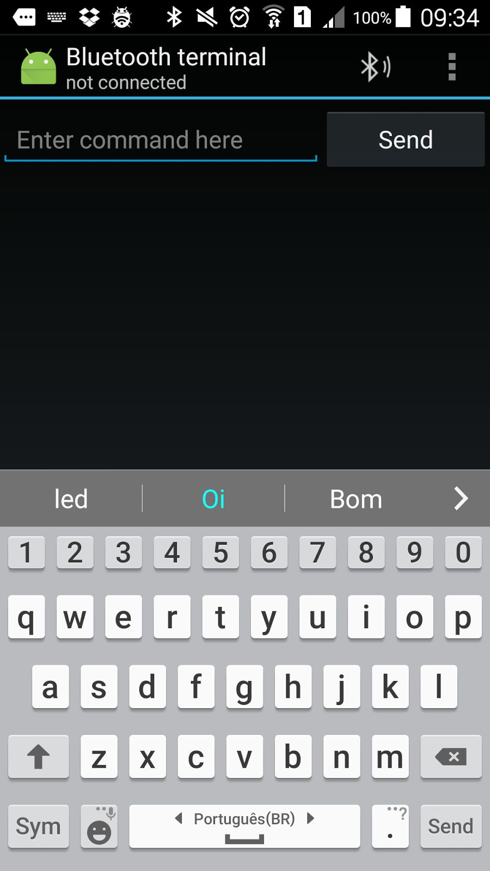
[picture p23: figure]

Aplicação desenvolvida para compreender o funcionamento do comunicador bluetooth.

2.5 Repositório de sons a serem executados pelo aplicativo

Pesquisa das escalas e dos instrumentos a serem tocados
Pesquisa para obtenção dos arquivos MIDI e mp3
Construção do repositório e classificação dos sons a serem tocados

21

### 2.6 Acompanhamento do cronograma

Atividade | Início | Fim | %
1 | Apresentação da disciplina e definição de equipes | 19/08/2015 | 19/08/2015 | 100
2 | Apresentação das propostas de projeto | 19/08/2015 | 26/08/2015 | 100
3 | Reapresentação das propostas de projeto e redefinição das equipes | 26/08/2015 | 02/09/2015 | 100
4 | Especificação e pesquisa de viabilidade do projeto para defesa e delimitação de um tema | 02/09/2015 | 09/09/2015 | 100
5 | Delimitação do microcontrolador a ser utilizado, quantidade de lasers e número de interceptações possíveis de serem feitas em cada feixe | 09/09/2015 | 19/09/2015 | 100
6 | Testes unitários com cada componente do sistema embarcado (testes com sonares, LDRs, envio de dados pelo Bluetooth) | 09/09/2015 | 28/10/2015 | 95
7 | Pesquisa e testes de API’s e bibliotecas para o desenvolvimento do aplicativo (testes para tocar áudio, receber dados pelo Bluetooth, construção de interface) | 09/09/2015 | 28/10/2015 | 100
8 | Elaboração do préprojeto | 19/09/2015 | 25/09/2015 | 100
9 | Pesquisa de sons para serem tocados no aplicativo | 23/09/2015 | 28/10/2015 | 100
10 | Desenvolvimento do aplicativo | 10/10/2015 | 22/11/2015 | 50
11 | Desenvolvimento do firmware | 10/10/2015 | 22/11/2015 | 10
12 | Testes dos sistemas integrados | 11/11/2015 | 22/11/2015 | 50
13 | Construção da estrutura física da harpa | 11/11/2015 | 22/11/2015 | 0
14 | Testes e ajustes finais para a apresentação e gravação do vídeo | 22/11/2015 | 25/11/2015 | 0

22

### 2.7 Dificuldades

01
Dificuldade: Funcionamento da fita de LEDs
Solução:Ainda não encontrada. Descobrir o que faz os segmentos da fita pararem de funcionar ao serem cortados. Em último caso, trocar as fitas por LED’s RGB simples.

02
Dificuldade: Tensão de alimentação das fitas de LED’s
Solução:Usar transistores para chaveamento ON/OFF. Controle de 3.3V para o acionamento de uma fita com tensão de alimentação de 12V. Aumentará o custo e tamanho do módulo sensorial. Solução ainda não implementada.

03
Dificuldade: Leitura imprecisa do sonar
Solução:Algumas vezes o sonar oferece uma leitura imprecisa ou discrepante. Adicionar algoritmo para tratar a leitura dos sensores no firmware antes de enviar os dados ao smartphone. Solução ainda não implementada.

04
Dificuldade: Manter o pareamento do bluetooth em múltiplas telas Solução:Criar um serviço que rode no background do aplicativo, mantendo o dispositivo conectadocom a harpa mesmo na mudança de tela.

23

### 2.8 Atividades futuras

1 | Resolver os problemas com a fita LED ou achar solução alternativa
2 | Integrar embarcado e smartphone para que uma nota possa ser tocada ao ser interceptado o feixe.
3 | Desenvolver firmware genérico para mais de um módulo sensorial.
4 | Replicar testes integrados com mais de um módulo sensorial.
5 | Fazer projeto de PCI para o módulo sensorial.
6 | Comprar materiais restantes.
7 | Definir protocolo de comunicação.
8 | Prosseguir com o desenvolvimento do modo “Tocar Livremente”, juntamente com os testes de integração.

24

### 3. ENTREGA 3 (AV3)

### 3.1 Projeto de PCI

Levantamento de requisitos do módulo sensorial (pinos de entrada e saída) Design do esquemático do módulo sensorial
Alocação de componentes e roteamento de trilhas em software CAD.
Ajustes no layout da placa para melhor performance da mesma
Finalização do layout

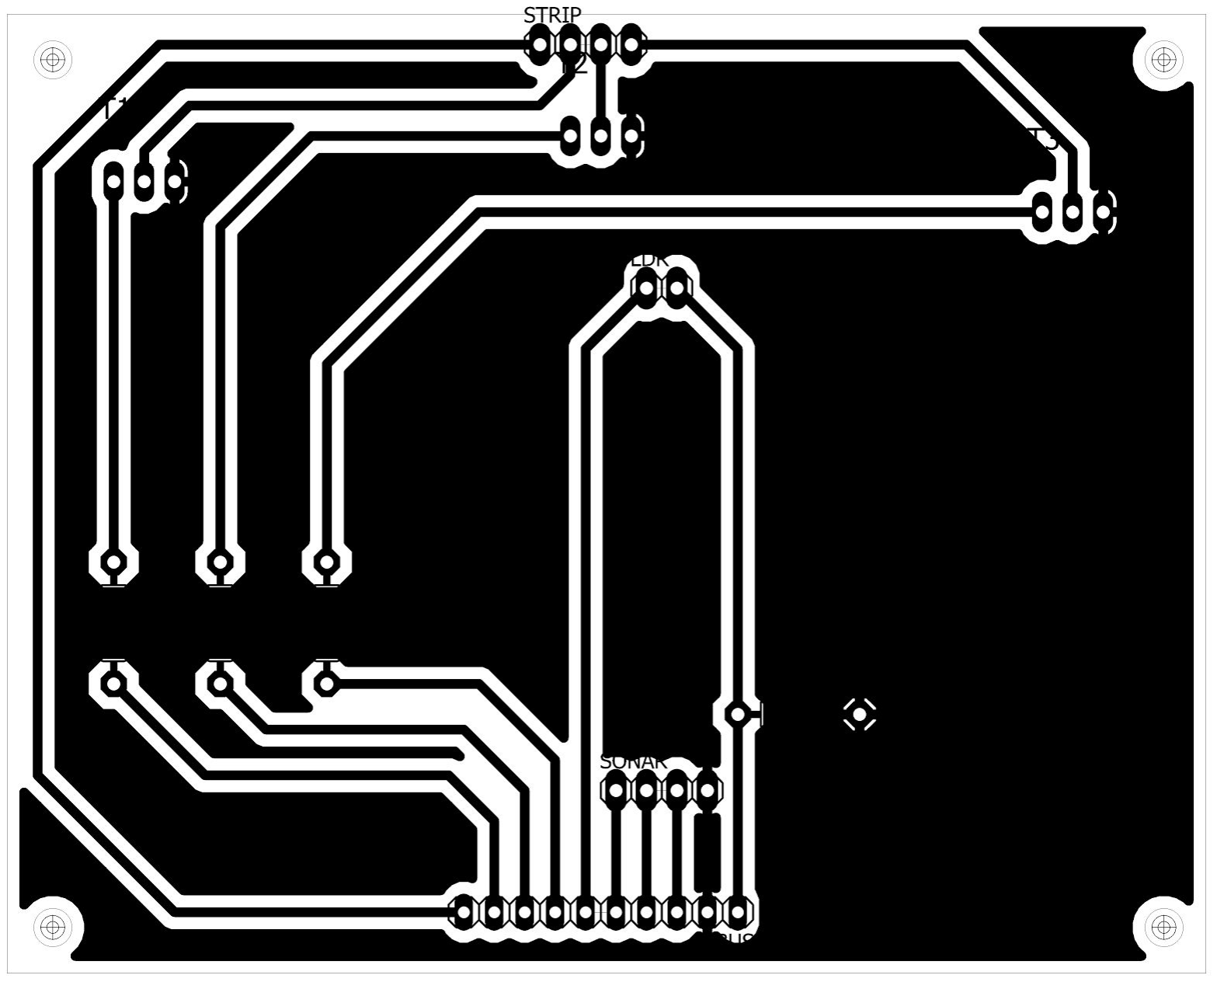
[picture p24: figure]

Layout do módulo sensorial

### 3.2 Entrega parcial do firmware

Testes unitários com cada componente do módulo sensorial.
Integração do módulo com os shift registers, transistores para chaveamento (3,3V 12V) e fita LED.
Desenvolvimento do firmware para uma única corda.
Integração do firmware com o comunicador bluetooth e estabelecimento de conexão entre sistema embarcado e dispositivo móvel.

25

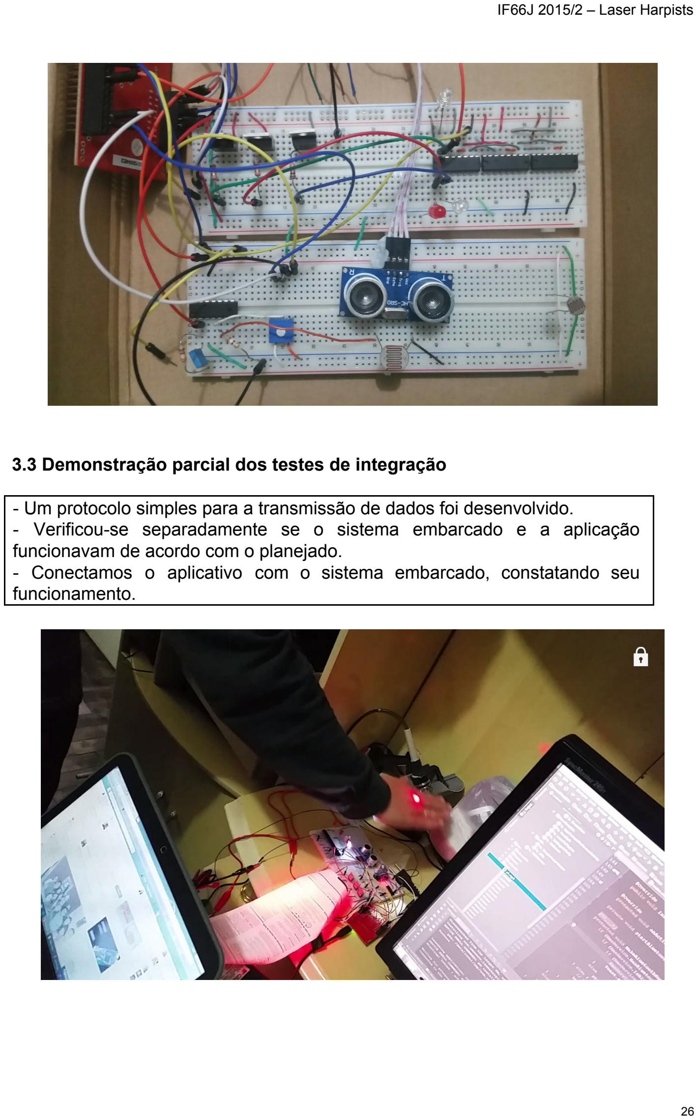
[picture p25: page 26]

### 3.3 Demonstração parcial dos testes de integração

Um protocolo simples para a transmissão de dados foi desenvolvido.
Verificouse separadamente se o sistema embarcado e a aplicação funcionavam de acordo com o planejado.
Conectamos o aplicativo com o sistema embarcado, constatando seu funcionamento.

26

### 3.4 Demonstração parcial do aplicativo

Estudo e observação sobre as taxas de transferência da entrega e recebimento das mensagens bluetooth pelo dispositivo móvel.
Adição dos arquivos .mid, para a execução do som.
Desenvolvimento do módulo “Tocar Livremente” totalmente funcional para uma corda da harpa (capaz de estabelecer conexão bluetooth com o sistema embarcado, gravar as musicas do usuário e trocar o módulo de reprodução).


Protótipo da tela principal do aplicativo desenvolvido

27


Protótipo do modo “Tocar Livremente” do aplicativo desenvolvido


Protótipo do modo “Aprenda a Tocar” do aplicativo desenvolvido

28

### 3.4 Acompanhamento do cronograma

Atividade | Início | Fim | %
1 | Apresentação da disciplina e definição de equipes | 19/08/2015 | 19/08/2015 | 100
2 | Apresentação das propostas de projeto | 19/08/2015 | 26/08/2015 | 100
3 | Reapresentação das propostas de projeto e redefinição das equipes | 26/08/2015 | 02/09/2015 | 100
4 | Especificação e pesquisa de viabilidade do projeto para defesa e delimitação de um tema | 02/09/2015 | 09/09/2015 | 100
5 | Delimitação do microcontrolador a ser utilizado, quantidade de lasers e número de interceptações possíveis de serem feitas em cada feixe | 09/09/2015 | 19/09/2015 | 100
6 | Testes unitários com cada componente do sistema embarcado (testes com sonares, LDRs, envio de dados pelo Bluetooth) | 09/09/2015 | 28/10/2015 | 100
7 | Pesquisa e testes de API’s e bibliotecas para o desenvolvimento do aplicativo (testes para tocar áudio, receber dados pelo Bluetooth, construção de interface) | 09/09/2015 | 28/10/2015 | 100
8 | Elaboração do préprojeto | 19/09/2015 | 25/09/2015 | 100
9 | Pesquisa de sons para serem tocados no aplicativo | 23/09/2015 | 28/10/2015 | 100
10 | Desenvolvimento do aplicativo | 10/10/2015 | 22/11/2015 | 40
11 | Desenvolvimento do firmware | 10/10/2015 | 22/11/2015 | 40
12 | Testes dos sistemas integrados | 11/11/2015 | 22/11/2015 | 30
13 | Construção da estrutura física da harpa | 11/11/2015 | 22/11/2015 | 5
14 | Testes e ajustes finais para a apresentação e gravação do vídeo | 22/11/2015 | 25/11/2015 | 0

29

### 3.5 Dificuldades

01
Dificuldade: Definir um layout adequado para as placas do módulo sensorial Solução: Para simplificar a confecção da placa, foi necessária a refatoração da mesma várias vezes, de modo que ela fosse de face simples e de um tamanho que permitisse a confecção de várias placas ao mesmo tempo.

02
Dificuldade: Imprecisão das medidas obtidas pelo sonar quando interceptado um laser
Solução: Corrigir a rotina que lê os dados do sonar, de forma a verificar qual o valor mais aceitável e próximo à altura de interceptação.

30

### 3.6 Atividades futuras

1 | Replicar código do firmware para múltiplas cordas
2 | Confeccionar PCIs
3 | Montar estrutura física
4 | Fazer integração com as demais cordas
5 | Finalizar modo “Tocar Livremente” no aplicativo
6 | Desenvolver modo “Aprenda a tocar”

31

### 4. ENTREGA 4 (AV4)

4.1Funcionamento do Projeto – Vídeo

Um video de 3 minutos (ATÉ 180 segundos, mas 180 segundos é o ideal).
A dinâmica da demonstração presente no video deve ser já a esperada para a demonstração ao vivo para a banca.
A equipe deve, em 3 minutos, ser capaz de demonstrar todas as funcionalidades técnicas do projeto.
O roteiro do video deve ser muito bem planejado e organizado.

4.2 Apresentação em Powerpoint

Todos da equipe apresentam.
Tempo máximo de 20 min.
Ao final apresentam o video (item 4.1).

### 4.3 Custos Reais do Projeto

Discriminação | $/un | Qtde | Valor
Sensor de distância ultrassônico HC-SR04 | R$ 8,13 | 8 | R$ 65,04
Diodo laser | R$ 7,03 | 8 | R$ 56,24
CI 74HC595 (shiftregister 8 bits) | R$ 1,50 | 3 | R$ 4,50
CI ULN2003 | R$ 1,50 | 4 | R$ 6,00
LDR’s | R$ 3,20 | 8 | R$ 25,60
CI LM339 (comparador) | R$ 0,75 | 2 | R$ 1,50
Fita LED 1M | R$ 20,00 | 1 | R$ 20,00
Header fêmea curvado (40 pinos) | R$ 2,70 | 1 | R$ 2,70
Placa Fenolite 20x20 | R$ 10,00 | 1 | R$ 10,00
Impressão papel couchê | R$ 2,00 | 1 | R$ 2,00
Header fêmea 40 pinos | R$ 1,45 | 1 | R$ 1,45
Cabo flat (1 metro) | R$ 2,85 | 4 | R$ 11,40
Conectores cabo flat | R$ 0,65 | 16 | R$ 10,40
Terminal modu | R$ 0,10 | 32 | R$ 3,20
Header macho 90 graus (40 pinos) | R$ 2,90 | 1 | R$ 2,90
Barra de pinos fêmea (40 pinos) | R$ 1,50 | 1 | R$ 1,50
Barra de pinos macho (40 pinos) | R$ 1,00 | 4 | R$ 4,00
Placa perfurada 10x30 | R$ 27,00 | 1 | R$ 27,00
Sockets para CIs | R$ 0,50 | 9 | R$ 4,50
Smartphone com sistema operacional Android | | 1 |
Microcontrolador Tiva C Launchpad | R$ 33,00 | 1 | R$ 33,00
Estrutura em madeira MDF | R$ 35,00 | 1 | R$ 35,00
Tubo de estanho de solda | R$ 6,00 | 1 | R$ 6,00

Total: R$ 527, 43

32

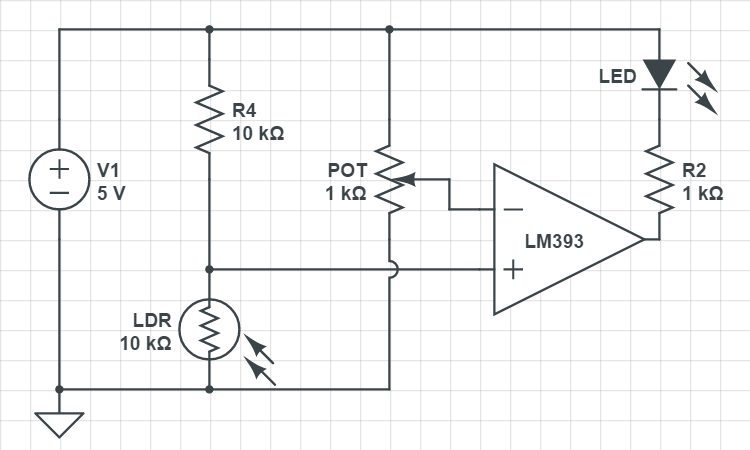
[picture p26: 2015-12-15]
hardware/detector_interceptacao.png

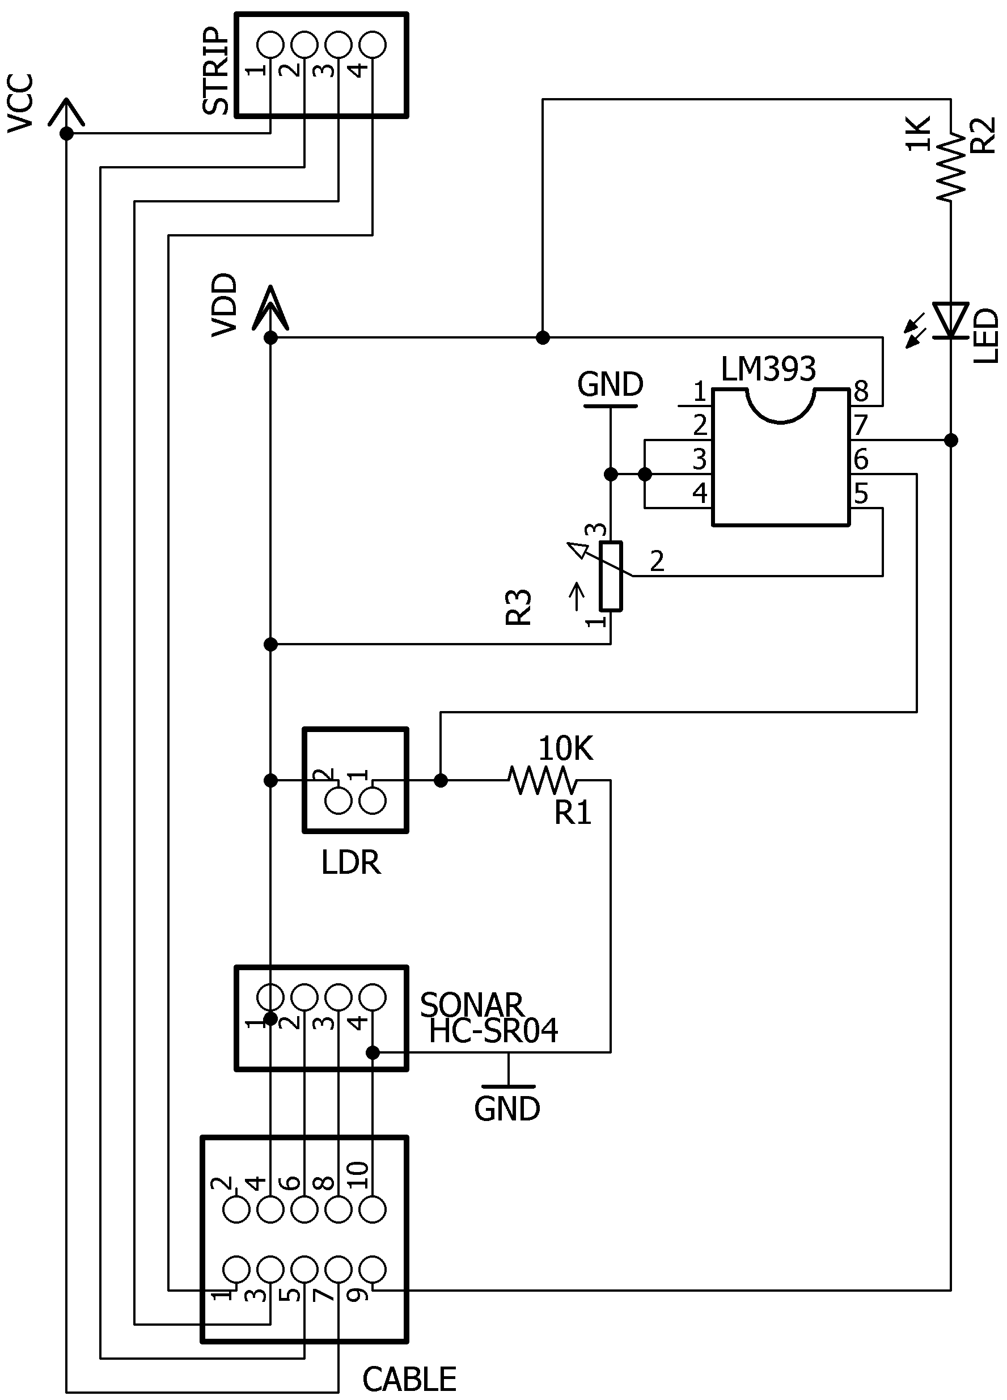
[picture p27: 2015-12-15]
hardware/pcb/module.png

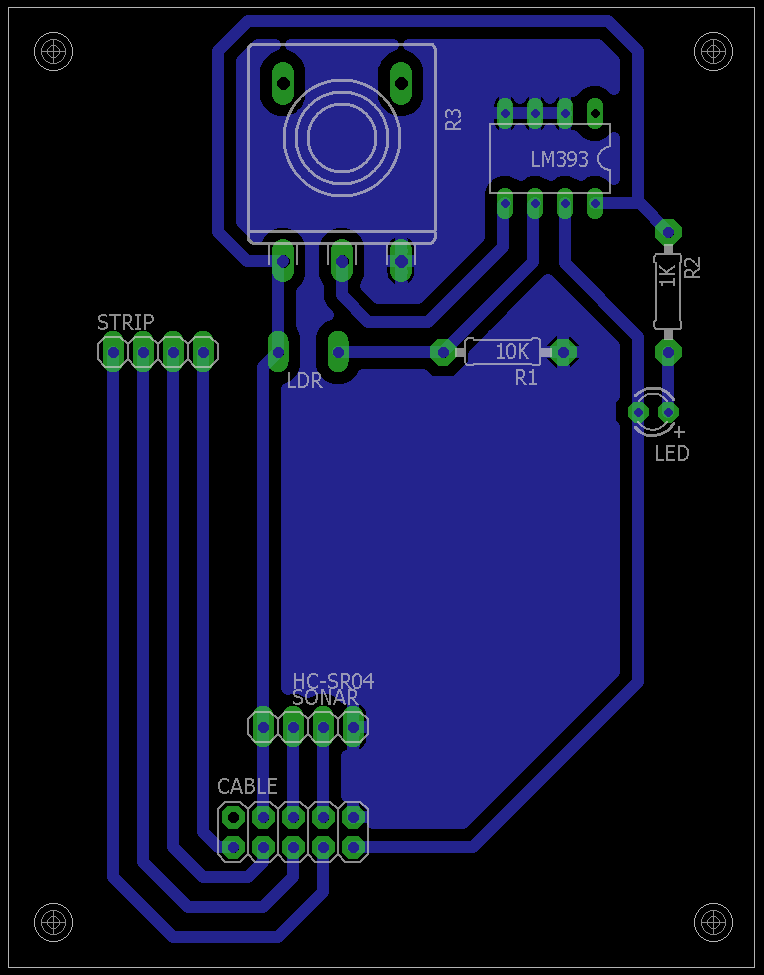
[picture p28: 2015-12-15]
hardware/pcb/modulo_sensorial.png

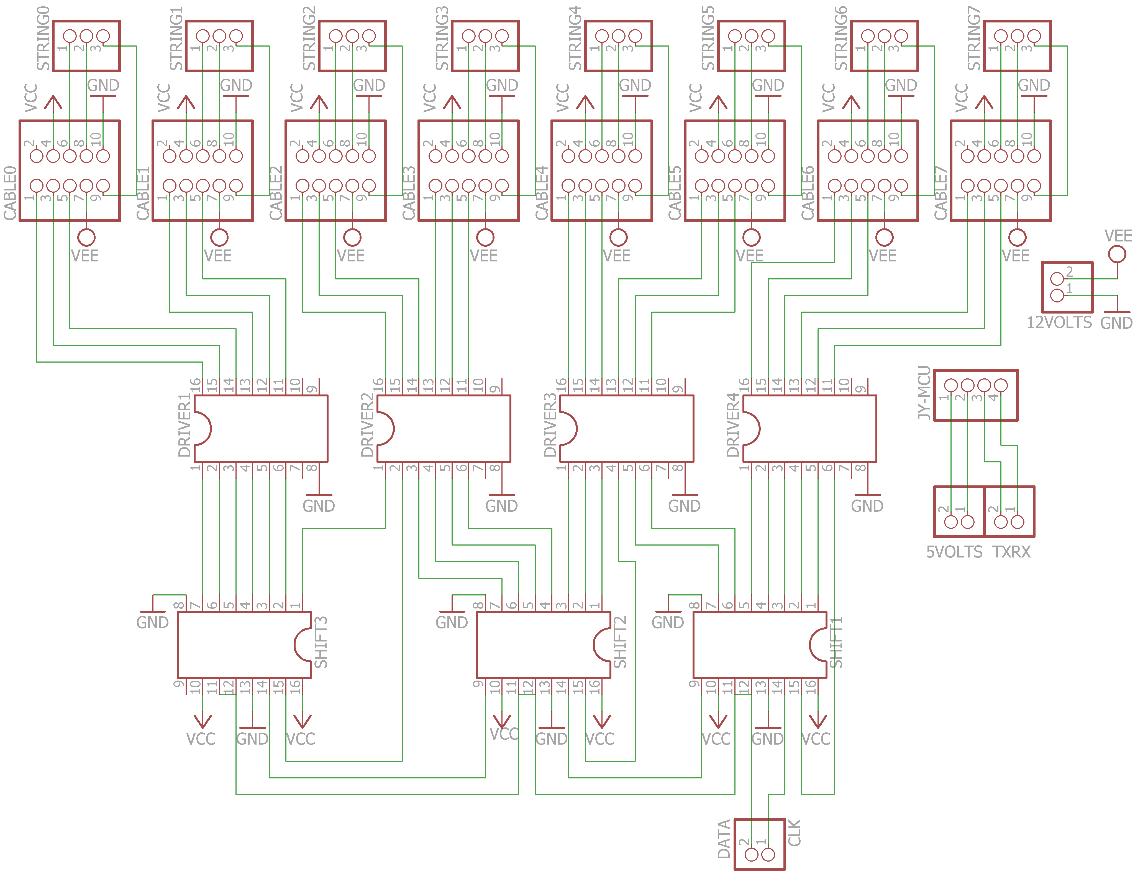
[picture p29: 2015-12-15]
hardware/pcb/central.png

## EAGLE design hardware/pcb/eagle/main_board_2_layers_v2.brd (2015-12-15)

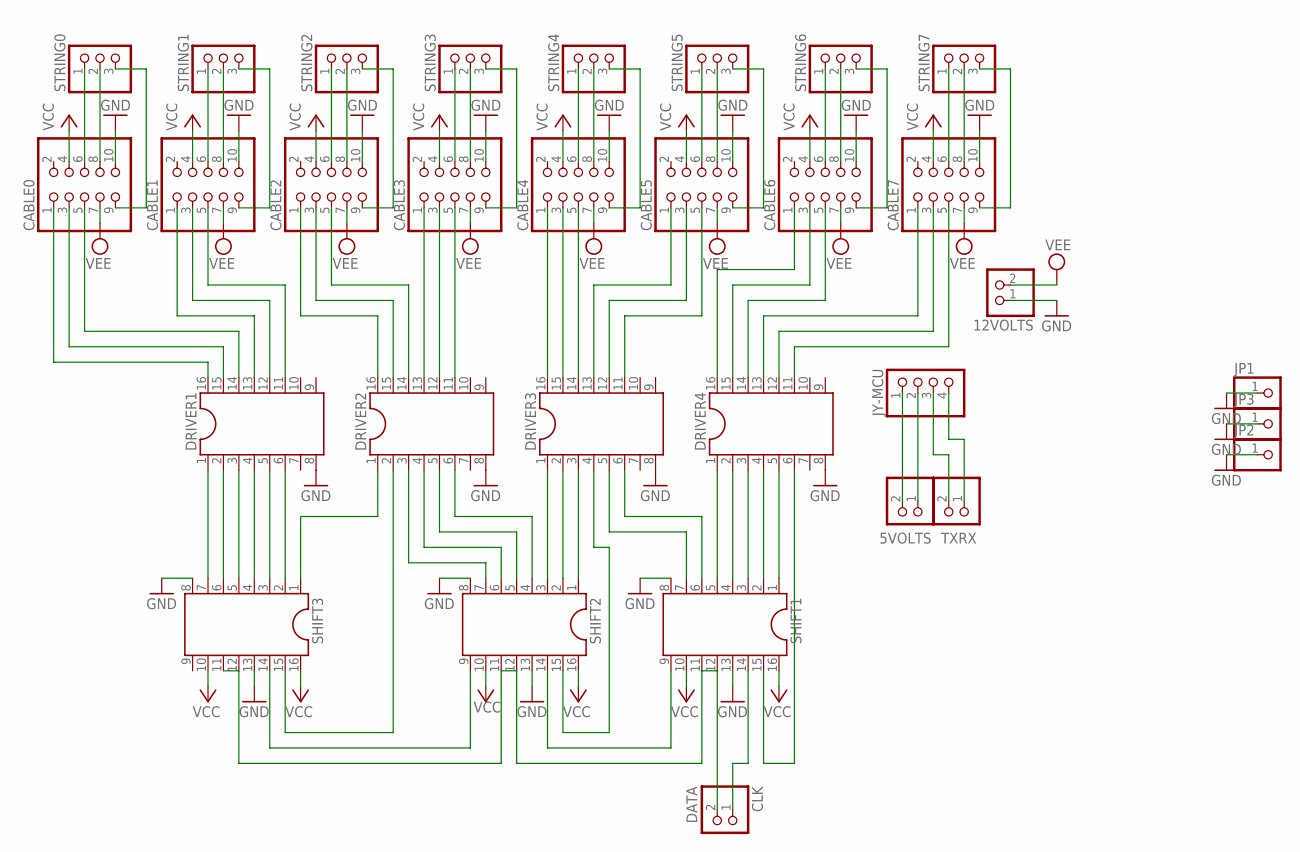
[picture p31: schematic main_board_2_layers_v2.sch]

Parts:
5VOLTS, 12VOLTS: PINHD-1X2; 1X02
CABLE0, CABLE1, CABLE2, CABLE3, CABLE4, CABLE5, CABLE6, CABLE7: PINHD-2X5; 2X05
CLK: DATA; 1X02
DRIVER1, DRIVER2, DRIVER3, DRIVER4: DIL16
JP1, JP2, JP3: PINHD-1X1; 1X01
JY-MCU: PINHD-1X4; 1X04
SHIFT1, SHIFT2, SHIFT3: DIL16
STRING0, STRING1, STRING2, STRING3, STRING4, STRING5, STRING6, STRING7: PINHD-1X3; 1X03
TXRX: PINHD-1X2; 1X02

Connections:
GND: 12VOLTS.1, CABLE0.10, CABLE1.10, CABLE2.10, CABLE3.10, CABLE4.10, CABLE5.10, CABLE6.10, CABLE7.10, DRIVER1.8, DRIVER2.8, DRIVER3.8, DRIVER4.8, JP1.1, JP2.1, JP3.1, SHIFT1.8, SHIFT1.13, SHIFT2.8, SHIFT2.13, SHIFT3.8, SHIFT3.13
unnamed: CABLE0.1, DRIVER1.16
unnamed: CABLE0.3, DRIVER1.15
unnamed: CABLE0.5, DRIVER1.14
unnamed: CABLE1.1, DRIVER1.13
unnamed: CABLE1.3, DRIVER1.12
unnamed: CABLE1.5, DRIVER1.11
unnamed: CABLE2.1, DRIVER2.16
unnamed: CABLE2.3, DRIVER2.15
unnamed: CABLE2.5, DRIVER2.14
unnamed: CABLE3.1, DRIVER2.13
unnamed: CABLE3.3, DRIVER2.12
unnamed: CABLE3.5, DRIVER2.11
unnamed: CABLE4.1, DRIVER3.16
unnamed: CABLE4.3, DRIVER3.15
unnamed: CABLE4.5, DRIVER3.14
unnamed: CABLE5.1, DRIVER3.13
unnamed: CABLE5.3, DRIVER3.12
unnamed: CABLE5.5, DRIVER3.11
unnamed: CABLE6.1, DRIVER4.16
unnamed: CABLE6.3, DRIVER4.15
unnamed: CABLE7.1, DRIVER4.13
unnamed: CABLE6.5, DRIVER4.14
unnamed: CABLE7.3, DRIVER4.12
unnamed: CABLE7.5, DRIVER4.11
unnamed: DRIVER4.5, SHIFT1.1
unnamed: DRIVER4.4, SHIFT1.2
unnamed: CABLE1.9, STRING1.3
unnamed: CABLE0.6, STRING0.1
unnamed: CABLE0.9, STRING0.3
unnamed: CABLE0.8, STRING0.2
unnamed: CABLE7.6, STRING7.1
unnamed: CABLE7.8, STRING7.2
unnamed: CABLE1.6, STRING1.1
unnamed: CABLE1.8, STRING1.2
unnamed: CABLE7.9, STRING7.3
unnamed: CABLE2.8, STRING2.2
unnamed: CABLE2.6, STRING2.1
unnamed: CABLE3.9, STRING3.3
unnamed: CABLE3.8, STRING3.2
unnamed: CABLE3.6, STRING3.1
unnamed: CABLE4.9, STRING4.3
unnamed: CABLE4.8, STRING4.2
unnamed: CABLE4.6, STRING4.1
unnamed: CABLE5.9, STRING5.3
unnamed: CABLE5.6, STRING5.1
unnamed: CABLE5.8, STRING5.2
unnamed: CABLE6.9, STRING6.3
unnamed: CABLE6.6, STRING6.1
unnamed: CABLE6.8, STRING6.2
unnamed: DRIVER4.3, SHIFT1.3
unnamed: DRIVER4.2, SHIFT1.4
unnamed: DRIVER4.1, SHIFT1.5
unnamed: DRIVER3.6, SHIFT1.6
unnamed: DRIVER3.5, SHIFT1.7
unnamed: DRIVER3.4, SHIFT2.15
unnamed: DRIVER3.3, SHIFT2.1
unnamed: DRIVER3.2, SHIFT2.2
unnamed: DRIVER3.1, SHIFT2.3
unnamed: DRIVER2.6, SHIFT2.4
unnamed: DRIVER2.5, SHIFT2.5
unnamed: DRIVER2.4, SHIFT2.6
unnamed: DRIVER2.3, SHIFT2.7
unnamed: DRIVER2.2, SHIFT3.15
unnamed: DRIVER2.1, SHIFT3.1
unnamed: DRIVER1.1, SHIFT3.7
unnamed: DRIVER1.2, SHIFT3.6
unnamed: DRIVER1.3, SHIFT3.5
unnamed: DRIVER1.4, SHIFT3.4
unnamed: DRIVER1.5, SHIFT3.3
unnamed: DRIVER1.6, SHIFT3.2
unnamed: 5VOLTS.2, JY-MCU.1
unnamed: 5VOLTS.1, JY-MCU.2
unnamed: JY-MCU.3, TXRX.2
unnamed: SHIFT1.9, SHIFT2.14
unnamed: SHIFT2.9, SHIFT3.14
unnamed: CLK.1, SHIFT1.14
unnamed: CLK.2, SHIFT1.11, SHIFT1.12, SHIFT2.11, SHIFT2.12, SHIFT3.11, SHIFT3.12
unnamed: CABLE2.9, STRING2.3
unnamed: JY-MCU.4, TXRX.1
VCC: CABLE0.4, CABLE1.4, CABLE2.4, CABLE3.4, CABLE4.4, CABLE5.4, CABLE6.4, CABLE7.4, SHIFT1.10, SHIFT1.16, SHIFT2.10, SHIFT2.16, SHIFT3.10, SHIFT3.16
VEE: 12VOLTS.2, CABLE0.7, CABLE1.7, CABLE2.7, CABLE3.7, CABLE4.7, CABLE5.7, CABLE6.7, CABLE7.7

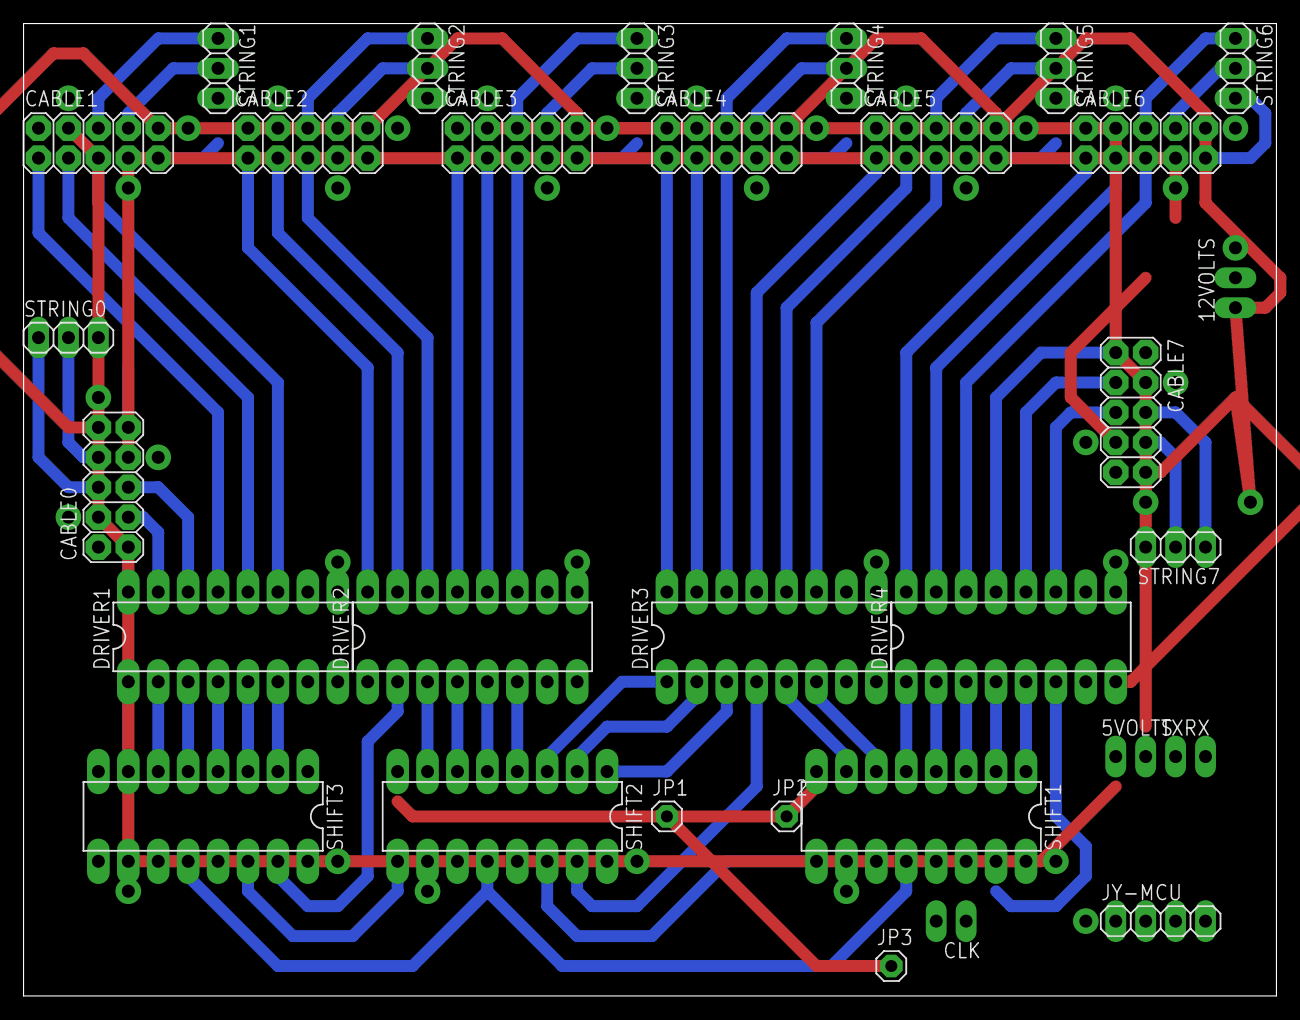
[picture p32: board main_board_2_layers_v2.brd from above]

Board: 2 copper layers, 106.3 x 82.5 mm, 31 parts (0 on the bottom side), 82 nets.

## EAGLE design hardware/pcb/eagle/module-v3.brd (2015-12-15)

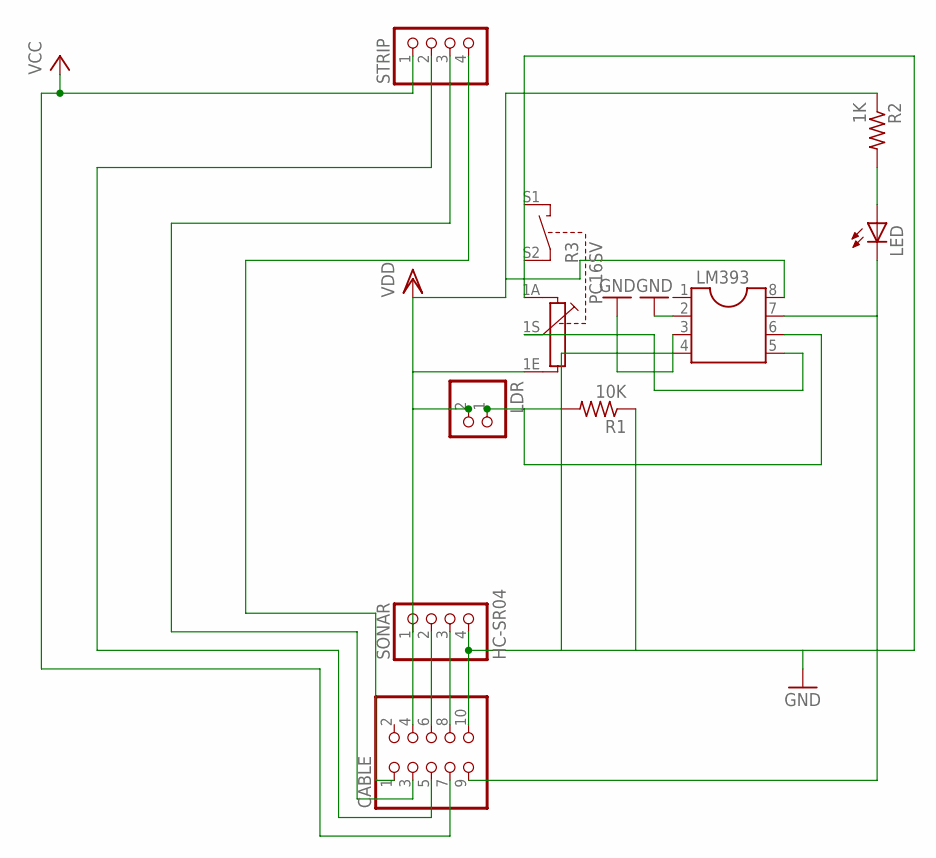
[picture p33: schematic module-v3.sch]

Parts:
CABLE: PINHD-2X5; 2X05
LDR: PINHD-1X2-DAIOGO; 1X02
LED: LED3MM
LM393: DIL8; DIL08
R1: 10K; 0207/10
R2: 1K; 0207/10
R3: PC16SV
SONAR: HC-SR04; 1X04
STRIP: PINHD-1X4; 1X04

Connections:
GND: CABLE.10, LM393.2, LM393.3, LM393.4, R1.1, R3.1A, SONAR.4
unnamed: LM393.5, R3.1S
unnamed: LDR.1, LM393.6, R1.2
unnamed: LED.A, R2.2
unnamed: CABLE.9, LED.K (C), LM393.7
unnamed: CABLE.8, SONAR.3
unnamed: CABLE.6, SONAR.2
unnamed: CABLE.1, STRIP.4
unnamed: CABLE.3, STRIP.3
unnamed: CABLE.5, STRIP.2
VCC: CABLE.7, STRIP.1
VDD: CABLE.4, LDR.2, LM393.8, R2.1, R3.1E, SONAR.1

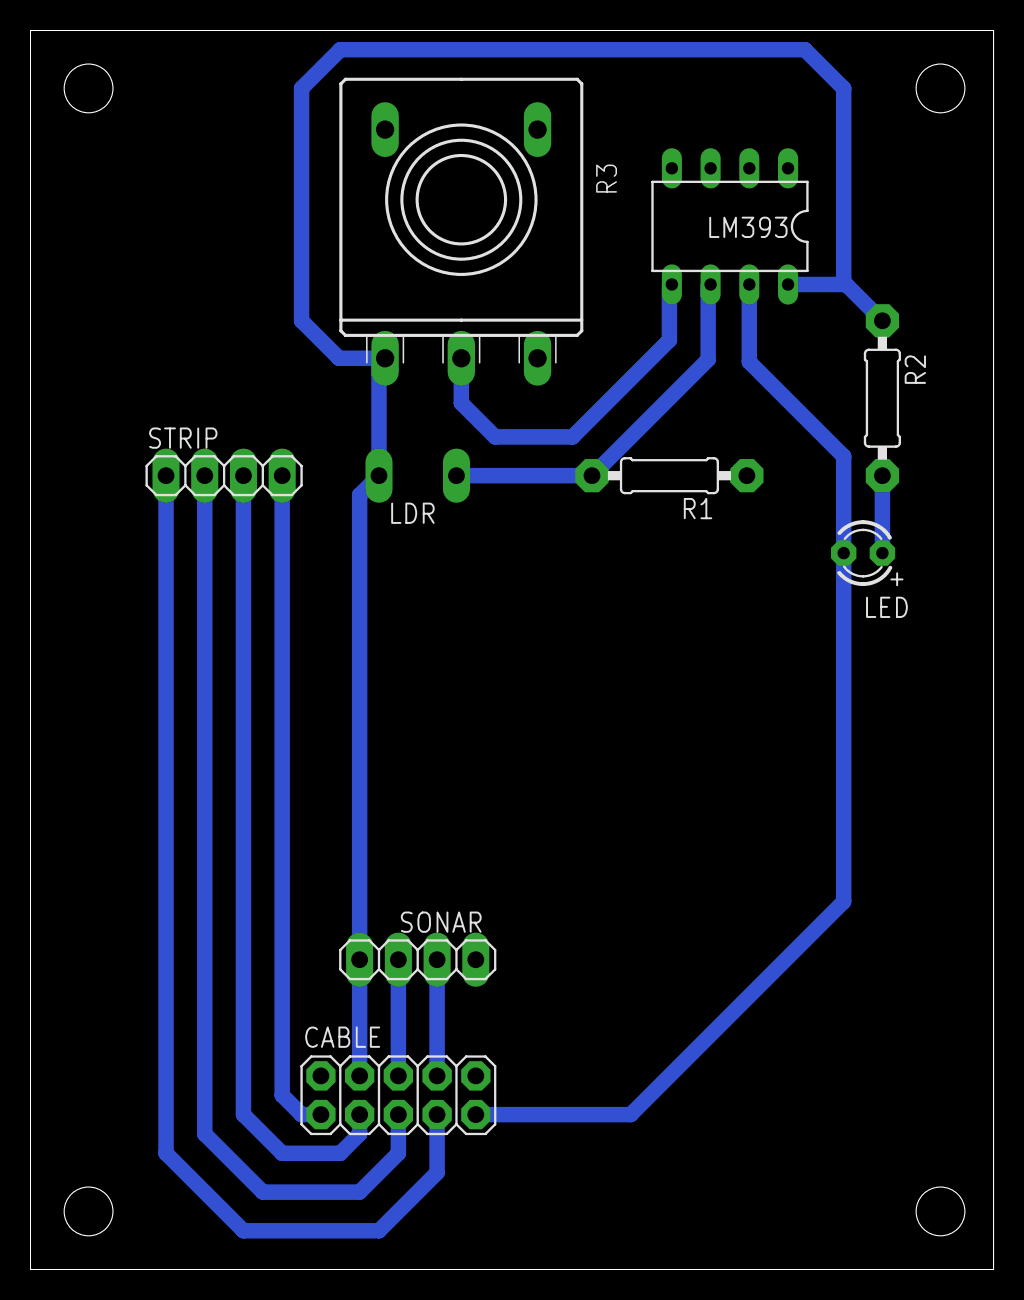
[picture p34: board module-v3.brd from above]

Board: 2 copper layers, 63.2 x 81.3 mm, 9 parts (0 on the bottom side), 12 nets.

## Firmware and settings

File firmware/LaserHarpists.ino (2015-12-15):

#ifndef bool
typedef unsigned char bool;
#define true 1
#define false 0
#endif

#define NUMBER_OF_LASERS 8

#define SPEED_OF_SOUND 	0.03434 //In cm/us
#define ECHO_INDEX 		1
#define TRIGGER_INDEX 	0

#define SR_CLOCK 15 //PB_3
#define RGB_DATA 14 //PE_0

#define GREEN	0
#define RED		1
#define BLUE	2
#define LIGHTOFF	3

const int LDR_PINS[ NUMBER_OF_LASERS ] = {30, 9, 27, 4, 11, 34, 38, 17}; //from sensor 0 to 7

const int DISTANCE_SENSOR_PINS[ NUMBER_OF_LASERS ][ 2 ] = {
	{28, 29},
	{7, 8},
	{25, 26},
	{2, 3},
	{13, 12},
	{35, 34},
	{40, 39},
	{19, 18}
};

unsigned int ldrInterruptFlags[NUMBER_OF_LASERS];
bool ldrInterruptBuffer[NUMBER_OF_LASERS];
unsigned int distance;
unsigned int colors[NUMBER_OF_LASERS];

void changeLaser0() {
  ldrInterruptFlags[0] = digitalRead(LDR_PINS[0]);  
}

void changeLaser1() {
  ldrInterruptFlags[1] = digitalRead(LDR_PINS[1]);  
}

void changeLaser2() {
  ldrInterruptFlags[2] = digitalRead(LDR_PINS[2]);  
}

void changeLaser3() {
  ldrInterruptFlags[3] = digitalRead(LDR_PINS[3]);  
}

void changeLaser4() {
  ldrInterruptFlags[4] = digitalRead(LDR_PINS[4]);  
}

void changeLaser5() {
  ldrInterruptFlags[5] = digitalRead(LDR_PINS[5]);  
}

void changeLaser6() {
  ldrInterruptFlags[6] = digitalRead(LDR_PINS[6]);  
}

void changeLaser7() {
  ldrInterruptFlags[7] = digitalRead(LDR_PINS[7]);  
}

void setup() {
	Serial.begin(9600);
	Serial5.begin(9600);

	for (int i; i < NUMBER_OF_LASERS; i++) {
		pinMode(LDR_PINS[i], INPUT);
		pinMode(DISTANCE_SENSOR_PINS[i][ECHO_INDEX], INPUT);
		pinMode(DISTANCE_SENSOR_PINS[i][TRIGGER_INDEX], OUTPUT);
                ldrInterruptBuffer[i] = LIGHTOFF;
	}
	
	attachInterrupt(LDR_PINS[0], changeLaser0, CHANGE);
	attachInterrupt(LDR_PINS[1], changeLaser1, CHANGE);
	attachInterrupt(LDR_PINS[2], changeLaser2, CHANGE);
	attachInterrupt(LDR_PINS[3], changeLaser3, CHANGE);
	attachInterrupt(LDR_PINS[4], changeLaser4, CHANGE);
	attachInterrupt(LDR_PINS[5], changeLaser5, CHANGE);
	attachInterrupt(LDR_PINS[6], changeLaser6, CHANGE);
	attachInterrupt(LDR_PINS[7], changeLaser7, CHANGE);

        pinMode( RGB_DATA, OUTPUT );
        pinMode( SR_CLOCK, OUTPUT );
        digitalWrite( SR_CLOCK, LOW );
        digitalWrite( RGB_DATA, LOW );
        
        lightsLedTape();
}

void SendToBluetooth(int laser, unsigned int height, boolean ioParam) {
	char str [6];
	str[0] = ((char) (laser + 'A'));

	if (ioParam) {
		str[1] = 'i';
	}
	else {
		str[1] = 'o';
	}

	if (height < 10) {
		str[2] = ((char) height + '0');
		str[3] = '\r';
		str[4] = '\n';
	}
	else if((10 <= height) && (height <= 99)) {
		int tmp = height / 10;
		str[2] = ((char) tmp + '0');
		tmp = height % 10;
		str[3] = ((char) tmp + '0');
		str[4] = '\r';
		str[5] = '\n';
	}
	Serial5.write(str);
}

unsigned int getDistance(int laserIntercepted) {
	int TRIGGER_PIN = DISTANCE_SENSOR_PINS[laserIntercepted][TRIGGER_INDEX];
	int ECHO_PIN = DISTANCE_SENSOR_PINS[laserIntercepted][ECHO_INDEX];
	digitalWrite(TRIGGER_PIN, HIGH);
	delayMicroseconds(10);
	digitalWrite(TRIGGER_PIN, LOW);
	unsigned int duration = pulseIn(ECHO_PIN, HIGH, 4100);
	unsigned int distance_cm = (duration / 2) * SPEED_OF_SOUND;

	return distance_cm;
}

void loop() {
	
	for (int i; i < NUMBER_OF_LASERS; i++) {
		if (ldrInterruptFlags[i] != ldrInterruptBuffer[i]) {
			ldrInterruptBuffer[i] = ldrInterruptFlags[i];
				
			Serial.print("Color ");
			Serial.print(i);
			Serial.print(" is ");
				
			if (ldrInterruptBuffer[i] == HIGH) {
				distance = getDistance(i);
				SendToBluetooth(i, distance, true);
				
				if ((0 <= distance) && (distance < 22)) {
					colors[i] = GREEN;
					Serial.println(" GREEN");
				}
				else if ((22 <= distance) && ( distance < 44)) {
					colors[i] = RED;
					Serial.println(" RED");
				}
				else if ((44 <= distance) && (distance <= 68)) {
					colors[i] = BLUE;
					Serial.println(" BLUE");
				}
				else {
					colors[i] = LIGHTOFF;
					Serial.println(" OFF");
				}
			}
			else {
				SendToBluetooth(i, 0, false);
				colors[i] = LIGHTOFF;
				Serial.println(" OFF");
			}



			lightsLedTape();
		}
	}
			
	if (Serial5.available() > 0) {
                char incomingByteBluetooth = Serial5.read();
                char comTmp = incomingByteBluetooth - 'A';

		if ((0 <= comTmp) && (comTmp < 24)) {
			colors[comTmp / 3] = comTmp % 3;
			lightsLedTape();
		}
		
		comTmp = incomingByteBluetooth - '0';
		
		if ((0 <= comTmp) && (comTmp < 8)) {
			colors[comTmp] = LIGHTOFF;
			lightsLedTape();
		}

		Serial.println(incomingByteBluetooth);
	}

}

void pulse( int numberOfPulses ) {
	for( int pulse = 0; pulse < numberOfPulses; pulse++ ) {
		digitalWrite( SR_CLOCK, HIGH );
		delayMicroseconds( 15 ); //Possível fonte de erro
		digitalWrite( SR_CLOCK, LOW );
	}
}

void lightsGreen( ) {
	pulse( 2 );
	digitalWrite( RGB_DATA, HIGH );
	pulse( 1 );
	digitalWrite( RGB_DATA, LOW );
}

void lightsBlue( ) {
	digitalWrite( RGB_DATA, HIGH );
	pulse( 1 );
	digitalWrite( RGB_DATA, LOW );
	pulse( 2 );
}

void lightsRed( ) {
	pulse( 1 );
	digitalWrite( RGB_DATA, HIGH );
	pulse( 1 );
	digitalWrite( RGB_DATA, LOW );
	pulse( 1 );
}

void lightsOff( ) {
	pulse( 3 );
}

void lightsLedTape() {

  	for (int i = 0; i < NUMBER_OF_LASERS; i++) {
		switch( colors[i] ) {
			case GREEN:
				lightsGreen();
				break;
			case RED:
				lightsRed();
				break;
			case BLUE:
				lightsBlue();
				break;
			default:
				lightsOff();
				break;
		}
	}
	//According to Texas Instruments 74595 IC datasheet,
	//we need to send an extra pulse as the RCLR and RSCLK pins are short-circuited
	pulse( 1 );
	
}
